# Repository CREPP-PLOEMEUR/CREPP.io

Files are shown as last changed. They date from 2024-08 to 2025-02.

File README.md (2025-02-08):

<!-- ATOC -->
# Sommaire

- [CREPP.io](#crepp.io)
  - [Configuration](#configuration)
  - [Montage de la carte](#montage-de-la-carte)
  - [Programmation de la carte](#programmation-de-la-carte)
  - [Fonctions](#fonctions)
  - [Composants](#composants)
  - [Installation et Utilisation](#installation-et-utilisation)
  - [Auteurs](#auteurs)
  - [Remerciements](#remerciements)

<!-- ATOC -->

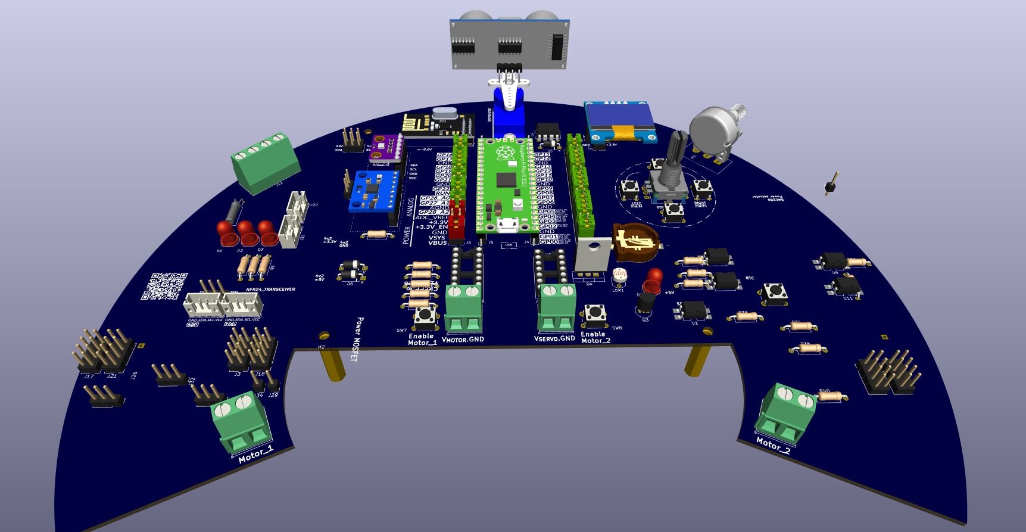
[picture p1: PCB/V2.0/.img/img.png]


# CREPP.io 

Ce projet consiste en la conception et la réalisation de cartes d'extension pour différents modules. La carte permet d'étendre les capacités de certains microcontrôleurs en ajoutant divers connecteurs, composants passifs et actifs, facilitant ainsi le développement de projets IoT (Internet des Objets). Elle est conçue pour offrir une interface facile d'utilisation pour la connexion de capteurs, d'afficheurs, de modules de communication, et d'autres périphériques.

Cette carte est le support de l'atelier Electronique Débutant pour le Club de Robotique et d'Electronique Programmable de Ploemeur (CREPP).

## Configuration

Pour programmer les cartes, nous utiliserons le framework **PlatformIO** 

Les instructions sont disponibles [sur cette page](SETUP.md)

## Montage de la carte 

Il convient tout d'abord de repérer le modèle de votre circuit :
Le numéro de version est sous le QRCode.

Les instructions de montage sont disponibles dans les fichiers suivants : 

- [Montage V1.0](PCB/V1.0/Assembly.md) - Version avec ESP12
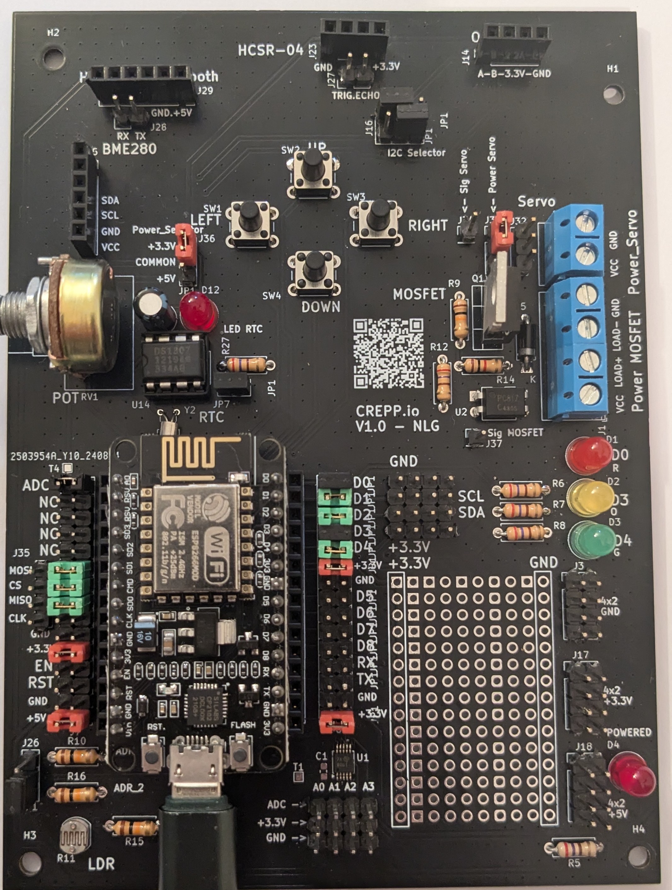
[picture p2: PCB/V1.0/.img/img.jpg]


- [Montage V1.1](PCB/V1.1/Assembly.md) - Version avec ESP12 amelioré
Description de l'image

- [Montage V2.0](PCB/V2.0/Assembly.md) - Version avec Raspberry Pi Pico-(W)
Description de l'image

## Programmation de la carte 

- [Codes V1.0](Codes/V1.X) - Code pour ESP12

- [Codes V2.0](Codes/V2.X) - Code pour Rapsberry Pi Pico W
## Fonctions

- **Connectivité étendue :** La carte propose plusieurs connecteurs (PinHeaders, Sockets, Bornes à vis) pour l'intégration facile de différents modules et capteurs.
- **Indicateurs visuels :** Des LEDs sont présentes pour indiquer l'état des signaux.
- **Contrôle manuel :** Des boutons-poussoirs permettent d'interagir directement avec la carte, utile pour des actions comme la navigation dans des menus ou la sélection de modes.
- **Horloge en temps réel :** Un module RTC (DS1307) est intégré pour fournir une mesure précise du temps.
- **Isolation et protection :** Un optocoupleur (PC817) est utilisé pour isoler électriquement certaines parties du circuit.

## Composants

- **Module ESP12 NodeMCU / Raspberry Pi Pico W:** Le cœur du projet
- **Convertisseur ADC (ADS1115) :** Permet des mesures analogiques précises.
- **Horloge RTC (DS1307) :** Fournit une temporisation en temps réel pour les applications nécessitant une précision horaire.
- **Optocoupleur (PC817) :** Assure l'isolation électrique entre différentes sections du circuit.
- **Transistor de puissance (IRF520) :** Gère la distribution de puissance pour les composants plus gourmands en énergie.

Le schéma du circuit et le design du PCB sont réalisés avec KiCad, un logiciel libre de conception de circuits électroniques. Les fichiers sources sont disponibles dans le dossier `/kicad_project`.

## Installation et Utilisation

- **Alimentation 5V ou 3.3V** pour la carte
- **Divers capteurs et modules** selon les besoins du projet (OLED, HC-SR04, BME280, etc.)

1. **Assemblez la carte** en soudant les composants selon le schéma fourni.
2. **Connectez le module** à la carte via les connecteurs dédiés.
3. **Branchez vos capteurs et modules** aux connecteurs correspondants (I2C, SPI, Analogiques, etc.).
5. **Téléversez votre code** sur le module ESP12 NodeMCU pour commencer à utiliser la carte d'extension.

Les contributions sont les bienvenues ! Si vous avez des idées d'amélioration ou des correctifs à proposer, n'hésitez pas à soumettre une Pull Request ou à ouvrir une Issue.

## Auteurs

- **LE GUERROUE Nicolas** - Concepteur principal

## Remerciements

Merci à la communauté open-source et aux contributeurs de KiCad pour avoir fourni les outils nécessaires à la réalisation de ce projet.

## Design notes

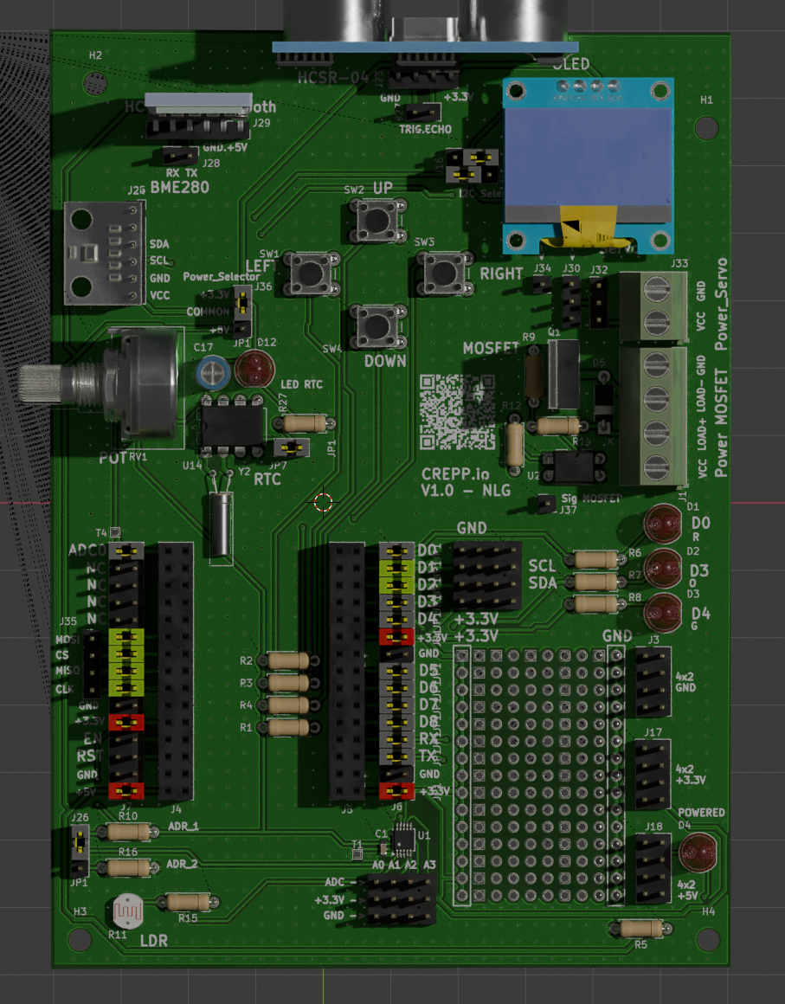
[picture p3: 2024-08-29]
Images/Top_View_BOARD.png

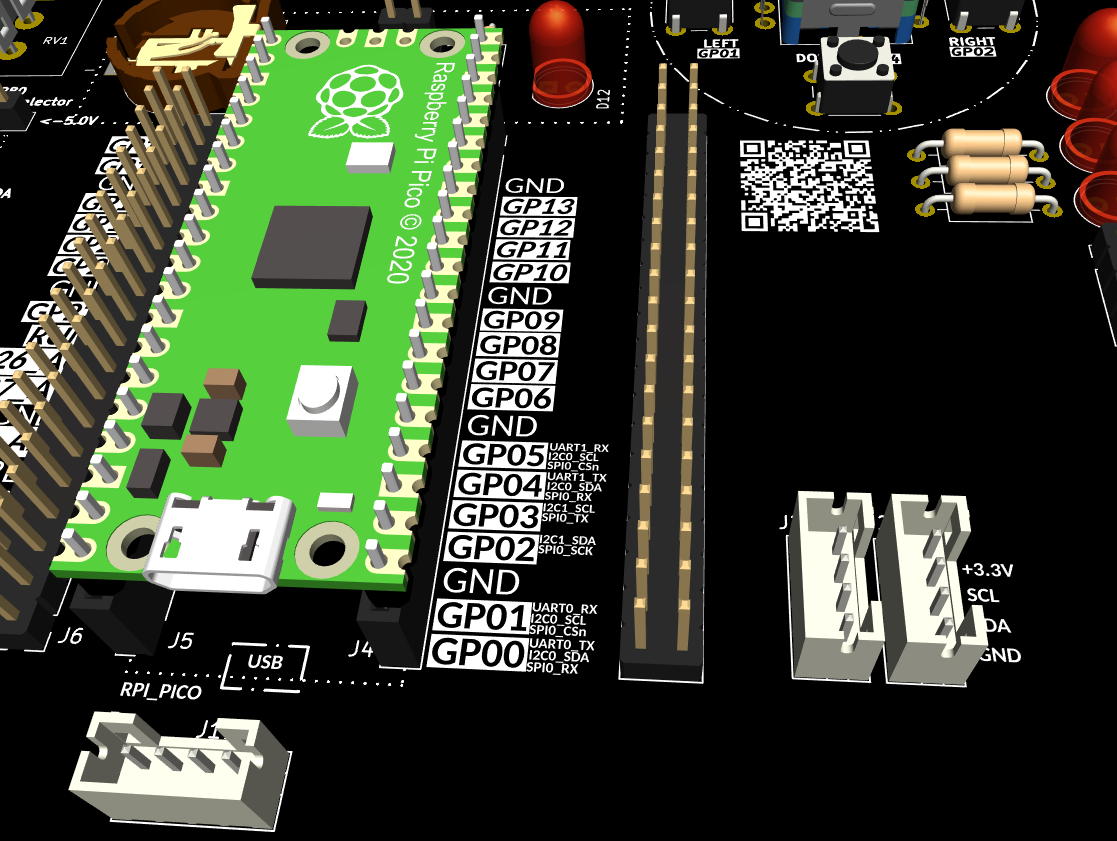
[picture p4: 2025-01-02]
PCB/V2.0/Images/Capture d’écran du 2024-11-20 23-39-54.png

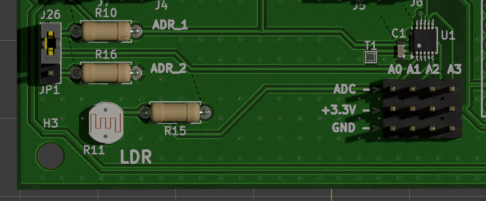
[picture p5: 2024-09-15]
Images/ADC.png

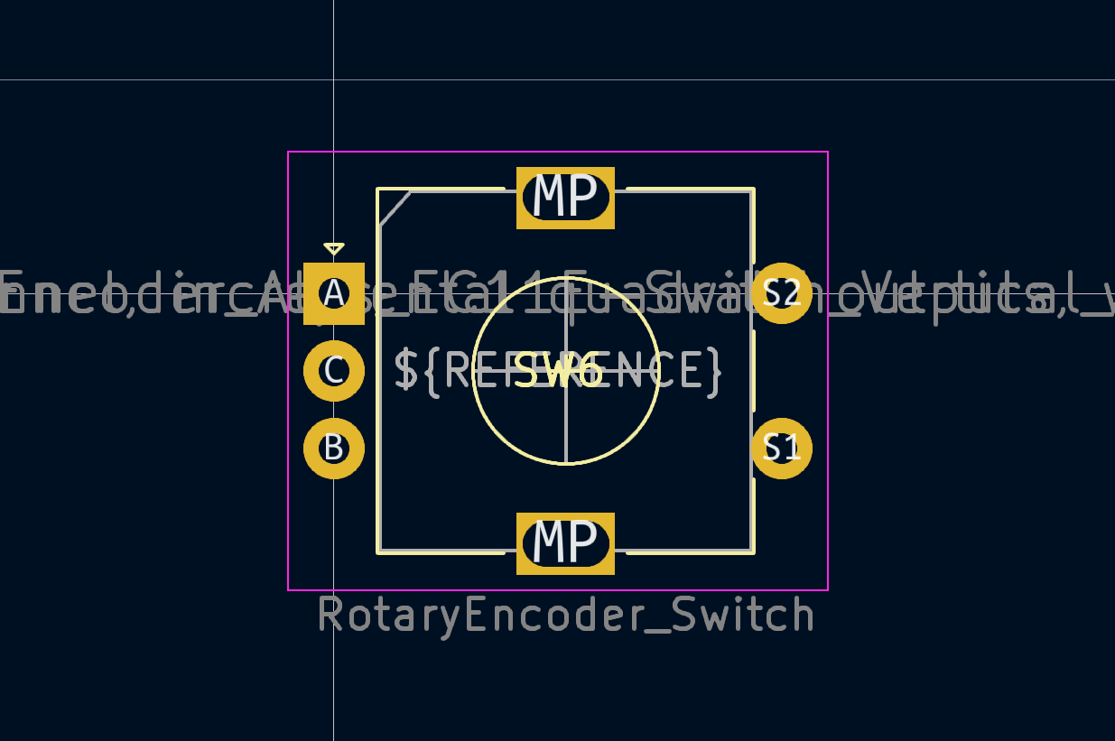
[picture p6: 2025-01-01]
PCB/V2.0/RotaryEncoder_Alps_EC11E-Switch_Vertical_H20mm.png

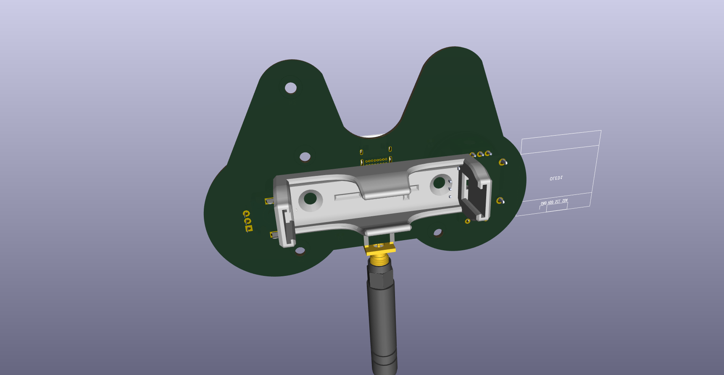
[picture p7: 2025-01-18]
PCB/CCR/CCR2.png

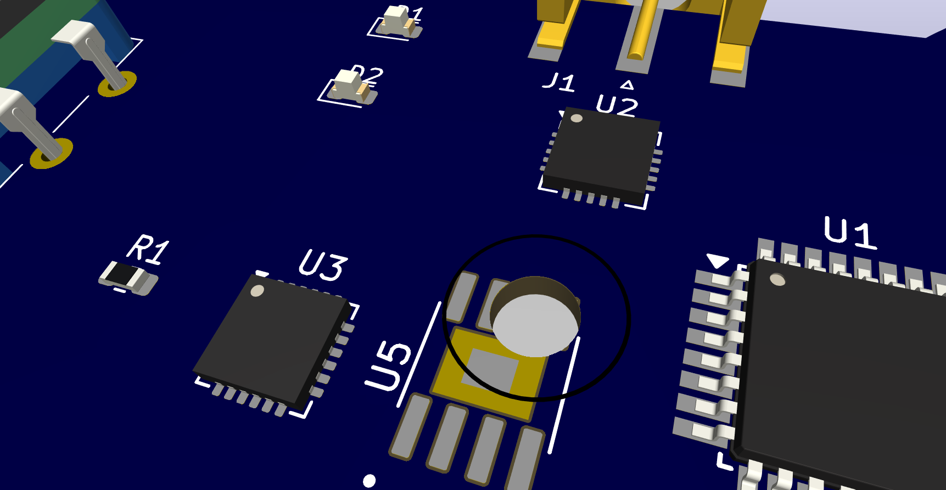
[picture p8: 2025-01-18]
PCB/CCR/CCR23.png

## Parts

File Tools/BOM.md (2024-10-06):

| Référence | Quantité | Désignation |
|---|---|---|
| R7,R27,R5,R12,R6,R8 | 6 | 270 Ω |
| RV1 | 1 | r_potentioMΩeter |
| R1,R2,R3,R16,R15,R4,R9,R10 | 8 | 10kΩ |
| R11 | 1 | r11 Ω |
| R14 | 1 | 1kΩ |
| D3,D1,D12,D4,D2 | 5 | LED |
| D5 | 1 | D |
| Q1 | 1 | IRF520 |
| J25 | 1 | BME |
| J20 | 1 | GND_Analog |
| J30 | 1 | Servo |
| J13,J15,J17,J3,J18 | 5 | Conn_02x04_Odd_Even |
| J4,J5 | 2 | Right_Connector |
| J19 | 1 | Analog_Inputs |
| J16 | 1 | I2C_Selector |
| J6,J12,J8,J9,J11,J10 | 6 | Right_Connector |
| J7 | 1 | Left_Connector |
| JP7 | 1 | Jumper |
| J33 | 1 | Screw_Terminal_01x02 |
| J23 | 1 | HC-SR |
| J21 | 1 | +3.3V_Analog |
| J35 | 1 | SPI_Connector |
| J29 | 1 | Conn_01x06_Socket |
| J36 | 1 | Power_Selector |
| J24 | 1 | BME_VIRTUAL |
| J26 | 1 | Addr_Selector |
| J37 | 1 | Sig_MOSFET |
| J1 | 1 | Screw_Terminal_01x04 |
| J32 | 1 | Power_Servo_Selector |
| J27 | 1 | SIG_HCSR04 |
| J14 | 1 | OLED_SOCKET |
| J28 | 1 | SIG_HC-05 |
| J34 | 1 | Sig_Servo |
| SW4 | 1 | SW_Down |
| SW2 | 1 | SW_Up |
| T1,T4 | 2 | TestPoint |
| U2 | 1 | PC817 |
| SW3 | 1 | SW_Right |
| U1 | 1 | ADS1115IDGS |
| C17 | 1 | 100nF |
| Y2 | 1 | 16MHz |
| SW1 | 1 | SW_Left |
| C1 | 1 | 100nF |
| U14 | 1 | DS1307+ |

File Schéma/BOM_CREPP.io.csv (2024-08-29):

Id | Référence | Empreinte | Quantité | Désignation | Fournisseur et réf
1 | R7,R27,R5,R12,R6,R8 | R_Axial_DIN0207_L6.3mm_D2.5mm_P7.62mm_Horizontal | 6 | 270
2 | JP1,JP1,JP1,JP1,JP1,JP1,JP1,JP1,JP1,JP1,JP1,JP1,JP1,JP1,JP1,JP1,JP1,JP1,JP1,JP1,JP1,JP1,JP1,JP1,JP1 | PinHeader_2x01_P2.54mm_Vertical | 25 | J2.54MM
3 | J25 | PinSocket_1x06_P2.54mm_Vertical | 1 | BME
4 | RV1 | Potentiometer_Alps_RK163_Single_Horizontal | 1 | R_Potentiometer
5 | J20 | PinHeader_1x04_P2.54mm_Vertical | 1 | GND_Analog
6 | J30 | PinHeader_1x03_P2.54mm_Vertical | 1 | Servo
7 | J13,J15,J17,J3,J18 | PinHeader_2x04_P2.54mm_Vertical | 5 | Conn_02x04_Odd_Even
8 | D3,D1,D12,D4,D2 | LED_D5.0mm | 5 | LED
9 | SW4 | SW_PUSH_6mm | 1 | SW_Down
10 | J4,J5 | PinSocket_2x15_P2.54mm_Vertical | 2 | Right_Connector
11 | J19 | PinHeader_1x04_P2.54mm_Vertical | 1 | Analog_Inputs
12 | J16 | PinHeader_2x03_P2.54mm_Vertical | 1 | I2C_Selector
13 | J22 | PinSocket_1x04_P2.54mm_Vertical | 1 | OLED_SOCKET_VIRTUAL
14 | J6,J12,J8,J9,J11,J10 | PinHeader_2x15_P2.54mm_Vertical | 6 | Right_Connector
15 | J7 | PinHeader_2x15_P2.54mm_Vertical | 1 | Left_Connector
16 | JP7 | PinHeader_1x02_P2.54mm_Vertical | 1 | Jumper
17 | J33 | TerminalBlock_Phoenix_MKDS-1,5-2_1x02_P5.00mm_Horizontal | 1 | Screw_Terminal_01x02
18 | SW2 | SW_PUSH_6mm | 1 | SW_Up
19 | R1,R2,R3,R16,R15,R4,R9,R10 | R_Axial_DIN0207_L6.3mm_D2.5mm_P7.62mm_Horizontal | 8 | 10k
20 | J23 | PinSocket_1x04_P2.54mm_Vertical | 1 | HC-SR
21 | T1,T4 | TestPoint_Pad_1.0x1.0mm | 2 | TestPoint
22 | J21 | PinHeader_1x04_P2.54mm_Vertical | 1 | +3.3V_Analog
23 | U2 | DIP-4_W7.62mm | 1 | PC817
24 | J35 | PinHeader_1x04_P2.54mm_Vertical | 1 | SPI_Connector
25 | SW3 | SW_PUSH_6mm | 1 | SW_Right
26 | D5 | D_A-405_P7.62mm_Horizontal | 1 | D
27 | U1 | TSSOP-10_3x3mm_P0.5mm | 1 | ADS1115IDGS
28 | J29 | PinSocket_1x06_P2.54mm_Vertical | 1 | Conn_01x06_Socket
29 | J36 | PinHeader_1x03_P2.54mm_Vertical | 1 | Power_Selector
30 | J24 | PinSocket_1x06_P2.54mm_Vertical | 1 | BME_VIRTUAL
31 | J26 | PinHeader_1x03_P2.54mm_Vertical | 1 | Addr_Selector
32 | J37 | PinHeader_1x01_P2.54mm_Vertical | 1 | Sig_MOSFET
33 | J31 | PinSocket_1x04_P2.54mm_Vertical | 1 | HC-05_VIRTUAL
34 | J1 | TerminalBlock_Phoenix_MKDS-1,5-4-5.08_1x04_P5.08mm_Horizontal | 1 | Screw_Terminal_01x04
35 | C17 | C_Radial_D5.0mm_H11.0mm_P2.00mm | 1 | 100nF
36 | J32 | PinHeader_1x03_P2.54mm_Vertical | 1 | Power_Servo_Selector
37 | J27 | PinHeader_1x02_P2.54mm_Vertical | 1 | SIG_HCSR04
38 | Y2 | Crystal_AT310_D3.0mm_L10.0mm_Horizontal | 1 | 16MHz
39 | Q1 | TO-220-3_Vertical | 1 | IRF520
40 | SW1 | SW_PUSH_6mm | 1 | SW_Left
41 | C1 | C_0603_1608Metric | 1 | 100nF
42 | J14 | PinSocket_1x04_P2.54mm_Vertical | 1 | OLED_SOCKET
43 | J28 | PinHeader_1x02_P2.54mm_Vertical | 1 | SIG_HC-05
44 | R11 | R_LDR_5.1x4.3mm_P3.4mm_Vertical | 1 | LDR07
45 | J34 | PinHeader_1x01_P2.54mm_Vertical | 1 | Sig_Servo
46 | R14 | R_Axial_DIN0207_L6.3mm_D2.5mm_P7.62mm_Horizontal | 1 | 1k
47 | U14 | DIP-8_W7.62mm | 1 | DS1307+
48 | J2 | PinSocket_1x04_P2.54mm_Vertical | 1 | HC-SR04_VIRTUAL

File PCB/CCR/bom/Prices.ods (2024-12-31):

Reference | Description | Quantité par carte | Prix de lot | Quantité par lot | Lot nécessaires | Quantité suffisantes | Prix unitaire | Livraison pour N cartes | Prix sur la carte | Quantité de cartes | 30
Puce NRF24 | NRF24 | 1 | 1,55 | 1 | 30 | OK | 1,55 | 10,8 | 1,55
Led rouges | Led rouge | 3 | 3,49 | 100 | 1 | OK | 0,0349 | 0 | 0,1047 |  |  | https://fr.aliexpress.com/item/1005003323707856.html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
Led vertes | LED vertes | 1 | 3,49 | 100 | 1 | OK | 0,0349 | 0 | 0,0349
Led jaunes | LED jaunes | 1 | 3,49 | 100 | 1 | OK | 0,0349 | 0 | 0,0349
L293D | L293D | 1 | 1,48 | 5 | 6 | OK | 0,296 | 2,93 | 0,296 |  |  | https://fr.aliexpress.com/item/1005007983665361.html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
Support DIP-16 |  | 1 | 1,14 | 20 | 2 | OK | 0,057 | 3,93 | 0,057
Connecteur JST 2mm |  | 2 | 2,72 | 100 | 1 | OK | 0,0272 | 0 | 0,0544 |  |  | https://fr.aliexpress.com/item/1005003431613901.html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
RPI pico |  | 1 | 8,28 | 1 | 30 | OK | 8,28 | 0 | 8,28
KF301-2P |  | 7 | 1,29 | 10 | 21 | OK | 0,129 | 0 | 0,903 |  |  | https://fr.aliexpress.com/item/1005008001886478.html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
OLED |  | 1 | 1,39 | 1 | 30 | OK | 1,39 | 0 | 1,39
MPU-6050 | Accéléromètre | 1 | 0,99 | 1 | 30 | OK | 0,99 | 0 | 0,99
74HC04 | Porte inverseuse | 1 | 1,91 | 10 | 3 | OK | 0,191 | 0 | 0,191 |  |  | https://fr.aliexpress.com/item/1005006870781173.html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
encodeur rotatif |  | 1 | 2,69 | 5 | 6 | OK | 0,538 | 0 | 0,538 |  |  | https://fr.aliexpress.com/item/1005007644083514.html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
Bouton poussoir |  | 7 | 1,44 | 50 | 5 | OK | 0,0288 | 2,83 | 0,2016
Moteur DC |  | 2 | 19,89 | 20 | 3 | OK | 0,9945 | 2 | 1,989 |  |  | https://fr.aliexpress.com/item/1005007447267197.html?scm_id=1007.40196.404796.0&scm-url=1007.40196.404796.0
BME280 | Attention vérifiez bien le voltage de fonctionnement de votre capteur, il en existe 2 versions. le capteur 3,3V comporte 6 broches, celui à 5V n'en possède que 4 | 1 | 3 | 1 | 30 | OK | 3 | 0 | 3
Résistances de 10k 1/4W |  | 10 | 0,58 | 100 | 3 | OK | 0,0058 | 2,61 | 0,058 |  |  | https://fr.aliexpress.com/item/1005003818444423.html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
Résistances de 1k 1/4W |  | 10 | 0,58 | 100 | 3 | OK | 0,0058 | 2,61 | 0,058 |  |  | https://fr.aliexpress.com/item/1005003818444423.html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
Résistances de 270 1/4W |  | 1 | 0,58 | 100 | 3 | OK | 0,0058 | 2,61 | 0,0058
Optocoupleur PC817 |  | 5 | 2,7 | 50 | 3 | OK | 0,054 | 0 | 0,27 |  |  | https://fr.aliexpress.com/item/1005006140298503.html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
HC-SR04 |  | 1 | 9,52 | 10 | 3 | OK | 0,952 | 0 | 0,952 |  |  | https://fr.aliexpress.com/item/1005007849944952.html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
Connecteur 2.54mm 40 |  | 6 | 2,42 | 20 | 10 | OK | 0,121 | 0 | 0,726
RTC DS1302 |  | 1 | 1,42 | 10 | 3 | OK | 0,142 | 0 | 0,142
 |  |  |  |  |  |  |  | 30,32 | 21,8263
 |  |  |  |  |  |  | Livraison par carte | 1,01066666666667
 |  |  |  |  |  |  | prix du PCB unitaire | 5
 |  |  |  |  |  |  | Total pour une carte | 27,8369666666667
 |  |  |  |  |  |  | Total Commande |  | 835,109

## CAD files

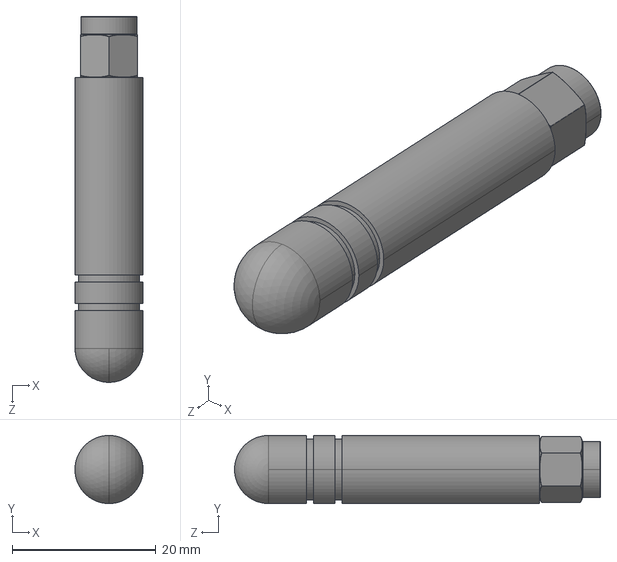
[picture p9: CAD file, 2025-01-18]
PCB/CCR/Parts/SMA_Antenna_3D.step
9.50 x 9.50 x 51.0 mm

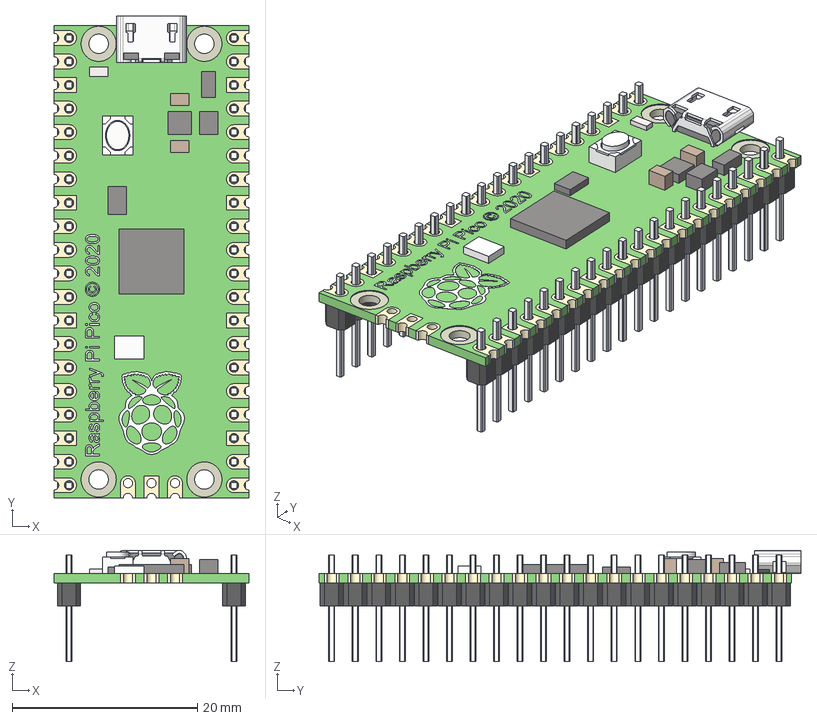
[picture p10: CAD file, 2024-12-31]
PCB/V2.0/VIRTUAL_PICO.step
21.0 x 52.0 x 12.0 mm
ножка x 20
ножка v3(Mirror) x 20

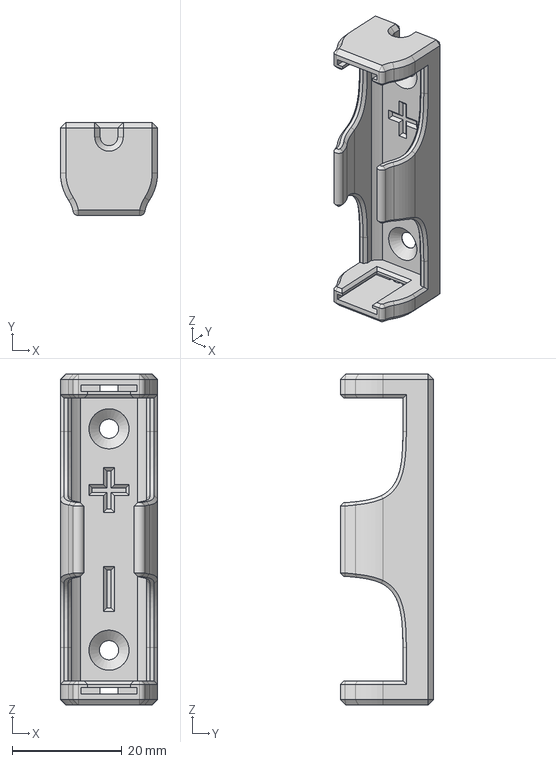
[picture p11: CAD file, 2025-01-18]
PCB/CCR/Parts/AA_14500 Battery Holder.step
17.7 x 17.0 x 60.3 mm

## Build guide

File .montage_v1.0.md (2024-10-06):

[Revenir sur la page d'accueil(github.com/CREPP-PLOEMEUR/crepp.io)

# Instructions de montage

Les instructions de montage concernent la version **1.0**

# Liste des composants

| Référence | Quantité | Désignation |
|---|---|---|
| D3,D1,D12,D4,D2 | 5 | LED |
| J14 | 1 | OLED_SOCKET |
| R7,R27,R5,R12,R6,R8 | 6 | 270 |
| J25 | 1 | BME |
| RV1 | 1 | R_Potentiometer |
| J20 | 1 | GND_Analog |
| J30 | 1 | Servo |
| J13,J15,J17,J3,J18 | 5 | Conn_02x04_Odd_Even |
| SW4 | 1 | SW_Down |
| J4,J5 | 2 | Right_Connector |
| J19 | 1 | Analog_Inputs |
| J16 | 1 | I2C_Selector |
| J6,J12,J8,J9,J11,J10 | 6 | Right_Connector |
| J7 | 1 | Left_Connector |
| JP7 | 1 | Jumper |
| J33 | 1 | Screw_Terminal_01x02 |
| SW2 | 1 | SW_Up |
| R1,R2,R3,R16,R15,R4,R9,R10 | 8 | 10k |
| J23 | 1 | HC-SR |
| T1,T4 | 2 | TestPoint |
| J21 | 1 | +3.3V_Analog |
| U2 | 1 | PC817 |
| J35 | 1 | SPI_Connector |
| SW3 | 1 | SW_Right |
| D5 | 1 | D |
| U1 | 1 | ADS1115IDGS |
| J29 | 1 | Conn_01x06_Socket |
| J36 | 1 | Power_Selector |
| J24 | 1 | BME_VIRTUAL |
| J26 | 1 | Addr_Selector |
| J37 | 1 | Sig_MOSFET |
| J1 | 1 | Screw_Terminal_01x04 |
| C17 | 1 | 100nF |
| J32 | 1 | Power_Servo_Selector |
| J27 | 1 | SIG_HCSR04 |
| Y2 | 1 | 16MHz |
| Q1 | 1 | IRF520 |
| SW1 | 1 | SW_Left |
| C1 | 1 | 100nF |
| J28 | 1 | SIG_HC-05 |
| R11 | 1 | R11 |
| J34 | 1 | Sig_Servo |
| R14 | 1 | 1k |
| U14 | 1 | DS1307+ |

# Remarque importante

Lors de la programmation de la carte, il ne faut pas que le Jumper D8 soit placé sur
son emplacement. Ou bien il faut presser le bouton LEFT lors du téléversement.

Ce problème est du au fait que la broche D8 doit être à l'état BAS lors de la programmation 
et que les boutons sont câblés avec une résistance qui impose un niveau HAUT par défaut.

# Remarques générales

On commence par monter les composants du plus bas au plus haut.

C'est à dire que si il y a des composants montés en surfaces (résistances, circuits intégrés, condensateurs...), il vaut mieux les monter 
car les composants plus hauts vont gêner.
On fait généralement les résistances traversantes dans un second ordre.

On termine donc par les grands composants (potentiomètres).

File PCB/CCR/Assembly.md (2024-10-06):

<!-- ATOC -->
# Sommaire

- [Instructions de montage](#instructions-de-montage)
- [Liste des composants](#liste-des-composants)
- [Plan de montage](#plan-de-montage)
- [Remarque importante](#remarque-importante)
- [Remarques générales](#remarques-generales)

<!-- ATOC -->
[Revenir sur la page d'accueil](http://github.com/CREPP-PLOEMEUR/crepp.io)

# Instructions de montage

Les instructions de montage concernent la version **1.0**.
Veuillez lire l'ensemble de cette page avant de commencer le montage.

# Liste des composants

| Référence | Quantité | Désignation |
|---|---|---|
| R7,R27,R5,R12,R6,R8 | 6 | 270 Ω |
| RV1 | 1 | r_potentiometer |
| R1,R2,R3,R16,R15,R4,R9,R10 | 8 | 10kΩ |
| R11 | 1 | r11 Ω |
| R14 | 1 | 1kΩ |
| D3,D1,D12,D4,D2 | 5 | LED |
| D5 | 1 | D |
| Q1 | 1 | IRF520 |
| J25 | 1 | BME |
| J20 | 1 | GND_Analog |
| J30 | 1 | Servo |
| J13,J15,J17,J3,J18 | 5 | Conn_02x04_Odd_Even |
| J4,J5 | 2 | Right_Connector |
| J19 | 1 | Analog_Inputs |
| J16 | 1 | I2C_Selector |
| J6,J12,J8,J9,J11,J10 | 6 | Right_Connector |
| J7 | 1 | Left_Connector |
| JP7 | 1 | Jumper |
| J33 | 1 | Screw_Terminal_01x02 |
| J23 | 1 | HC-SR |
| J21 | 1 | +3.3V_Analog |
| J35 | 1 | SPI_Connector |
| J29 | 1 | Conn_01x06_Socket |
| J36 | 1 | Power_Selector |
| J24 | 1 | BME_VIRTUAL |
| J26 | 1 | Addr_Selector |
| J37 | 1 | Sig_MOSFET |
| J1 | 1 | Screw_Terminal_01x04 |
| J32 | 1 | Power_Servo_Selector |
| J27 | 1 | SIG_HCSR04 |
| J14 | 1 | OLED_SOCKET |
| J28 | 1 | SIG_HC-05 |
| J34 | 1 | Sig_Servo |
| SW4 | 1 | SW_Down |
| SW2 | 1 | SW_Up |
| T1,T4 | 2 | TestPoint |
| U2 | 1 | PC817 |
| SW3 | 1 | SW_Right |
| U1 | 1 | ADS1115IDGS |
| C17 | 1 | 100nF |
| Y2 | 1 | 16MHz |
| SW1 | 1 | SW_Left |
| C1 | 1 | 100nF |
| U14 | 1 | DS1307+ |

# Plan de montage

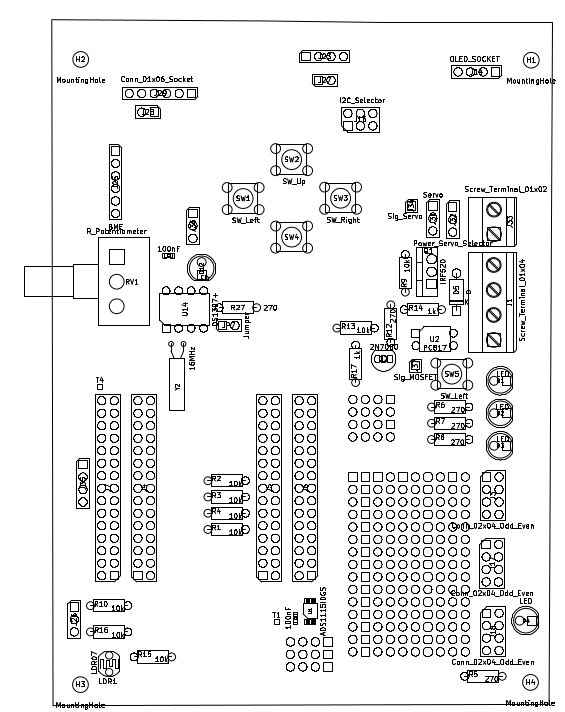
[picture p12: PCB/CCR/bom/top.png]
Plan de montage de la face supérieure


# Remarque importante

Lors de la programmation de la carte, il ne faut pas que le Jumper D8 soit placé sur
son emplacement. Ou bien il faut presser le bouton LEFT lors du téléversement.

Ce problème est du au fait que la broche D8 doit être à l'état BAS lors de la programmation 
et que les boutons sont câblés avec une résistance qui impose un niveau HAUT par défaut.

# Remarques générales

On commence par monter les composants du plus bas au plus haut.

C'est à dire que si il y a des composants montés en surfaces (résistances, circuits intégrés, condensateurs...), il vaut mieux les monter 
car les composants plus hauts vont gêner.
On fait généralement les résistances traversantes dans un second ordre.

On termine donc par les grands composants (potentiomètres).

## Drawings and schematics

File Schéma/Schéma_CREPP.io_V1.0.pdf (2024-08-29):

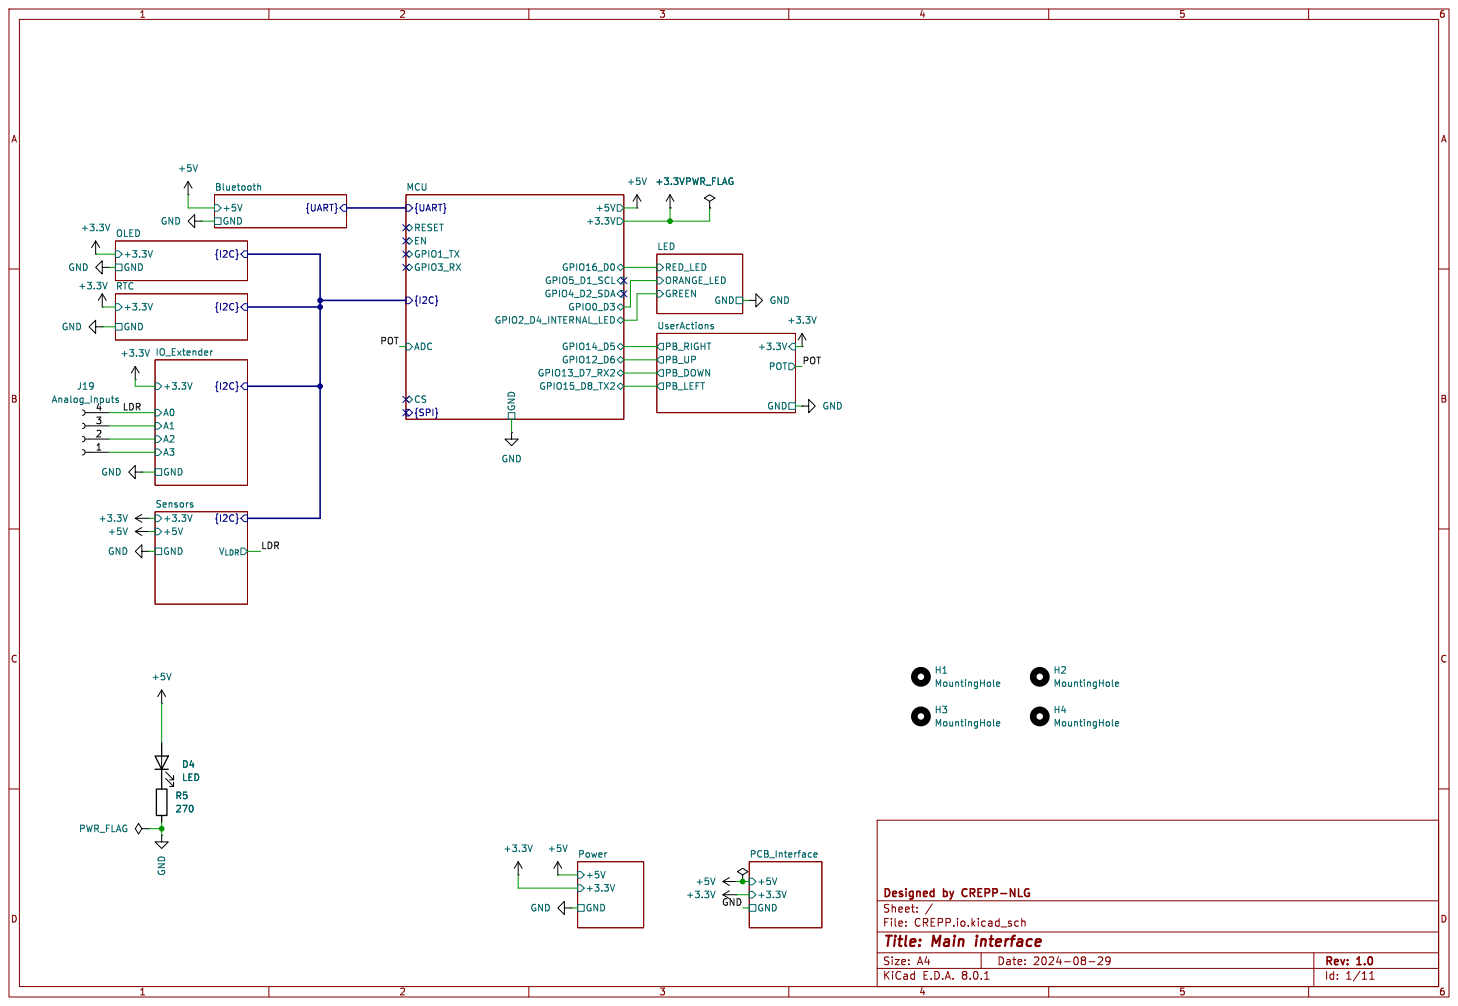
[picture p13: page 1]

Id: 1/11 Title: Main interface

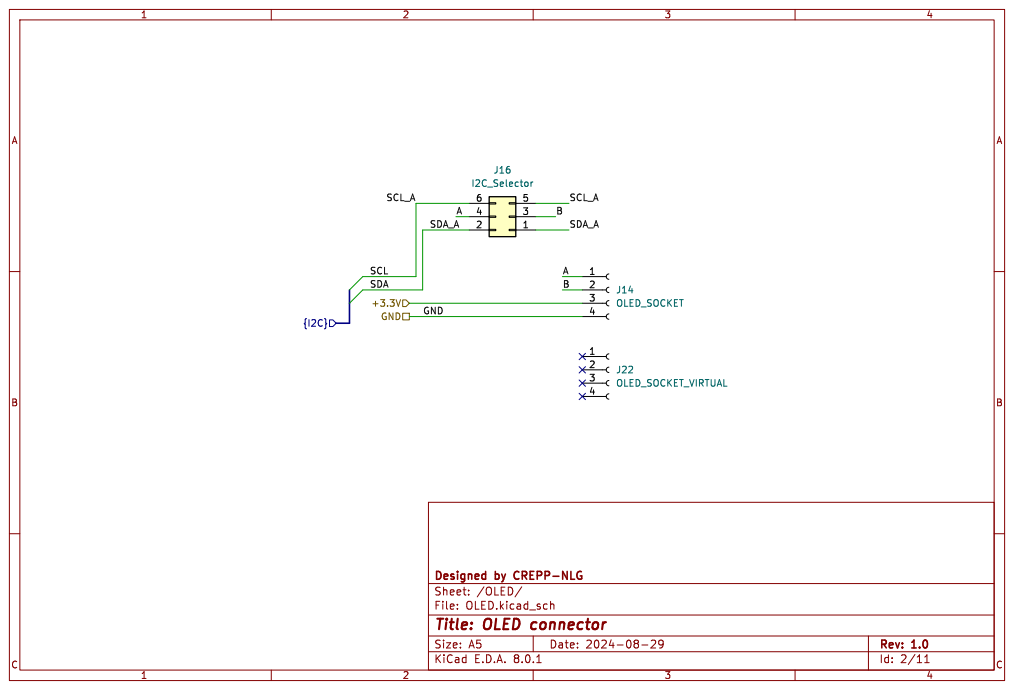
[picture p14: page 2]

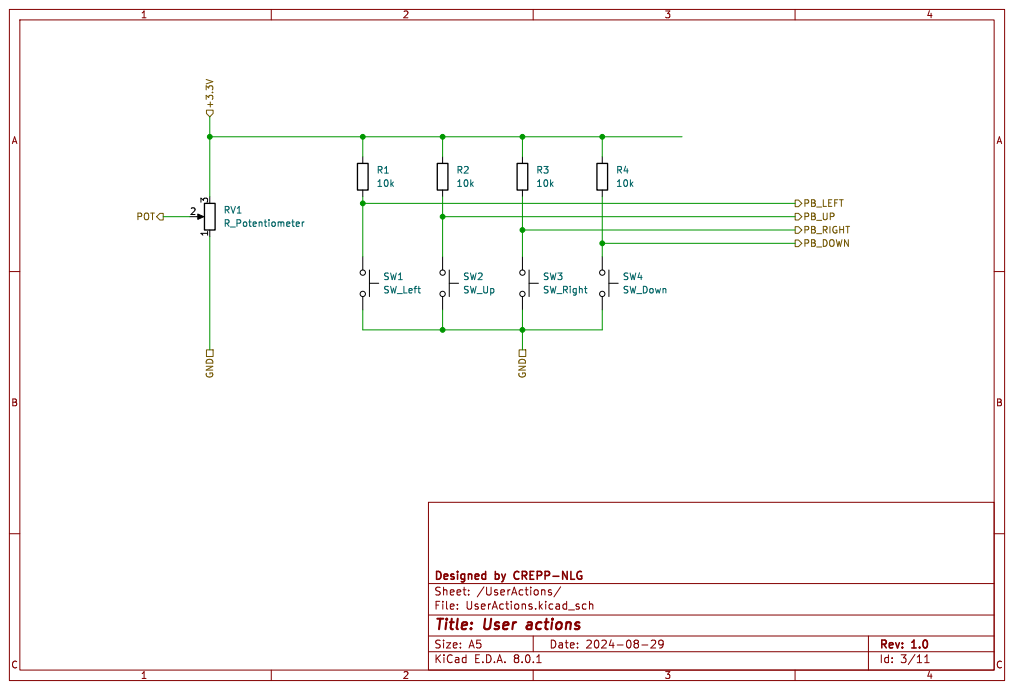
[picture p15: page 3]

Id: 3/11 Title: User actions

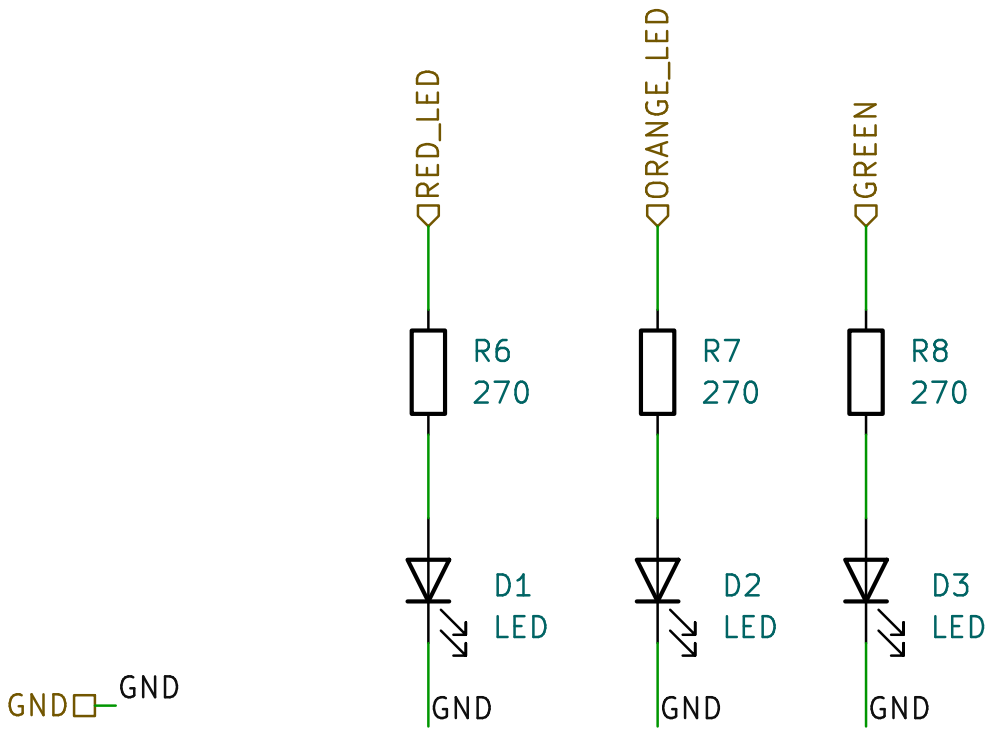
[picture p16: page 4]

Id: 4/11 Title: LED interface

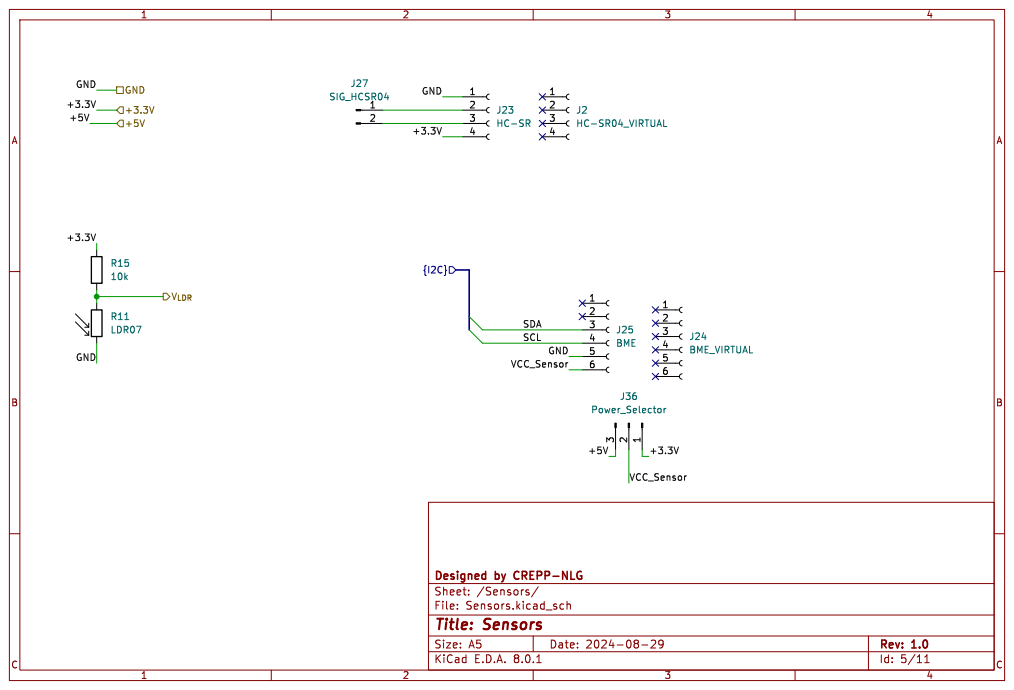
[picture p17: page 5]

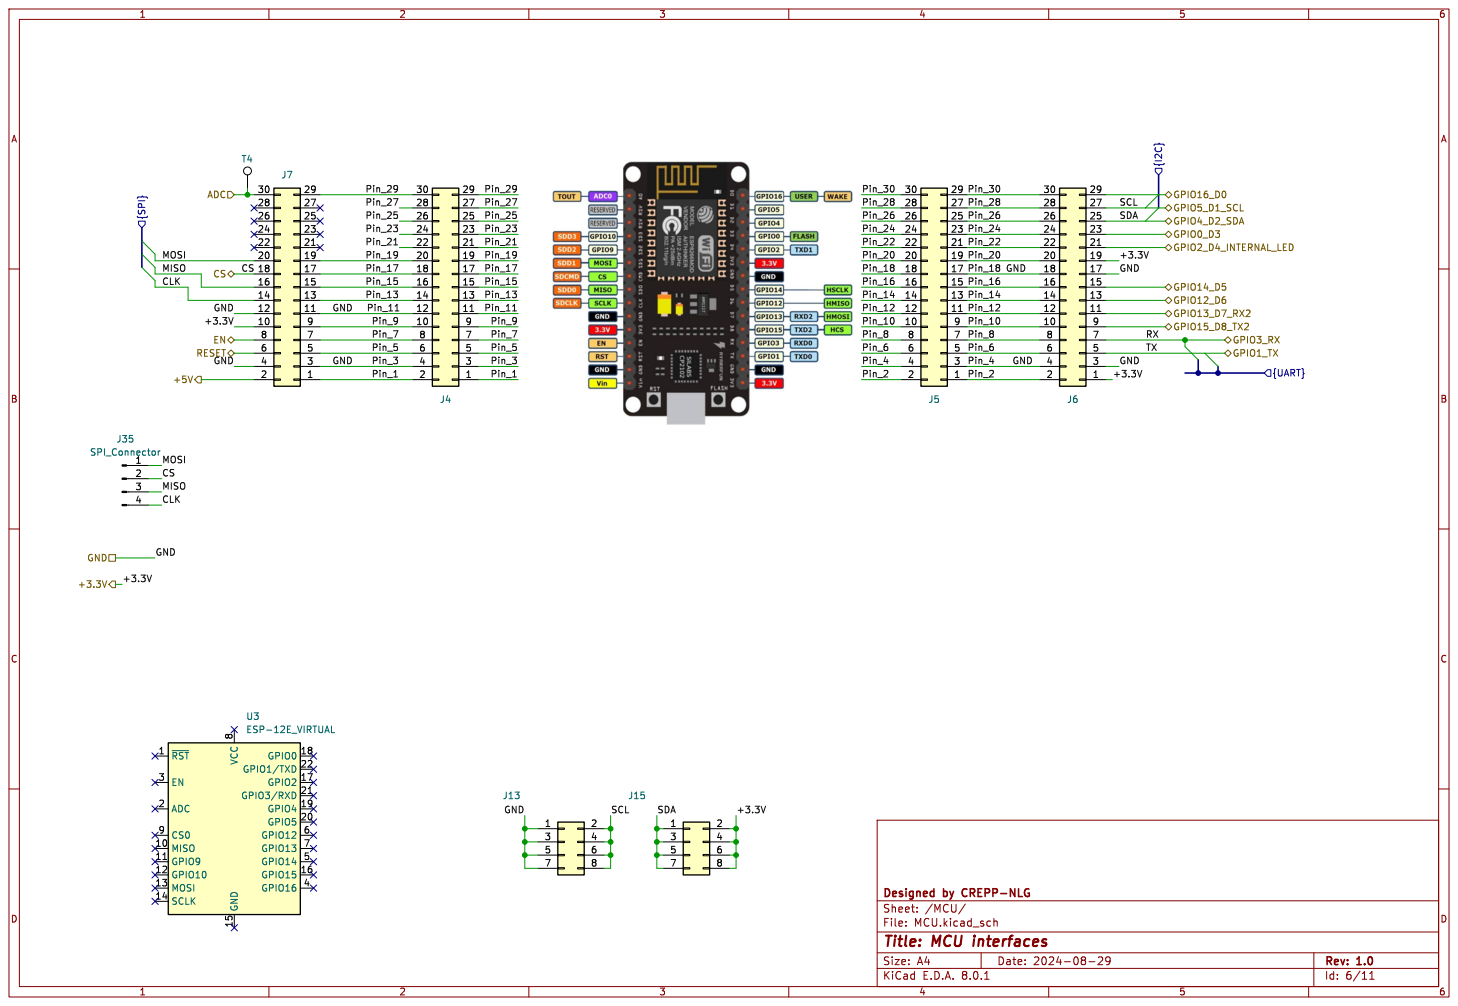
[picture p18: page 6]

Pin_22 Pin_6 Pin_26 Pin_20 Pin_18 GND MOSI CLK MISO

Id: 6/11 Title: MCU interfaces

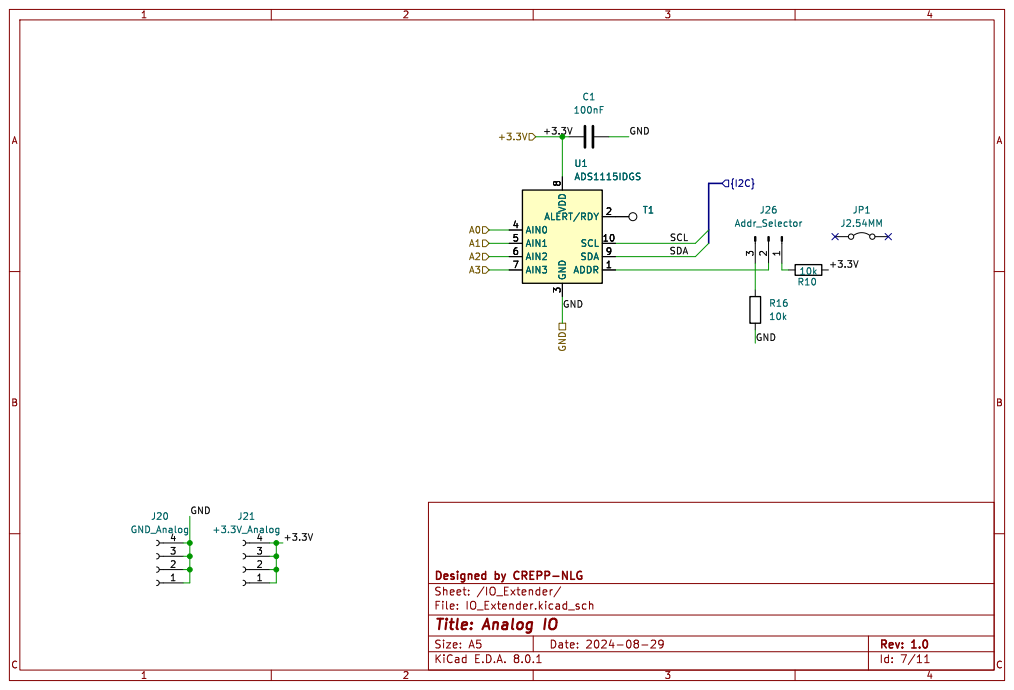
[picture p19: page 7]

Id: 7/11 Title: Analog IO

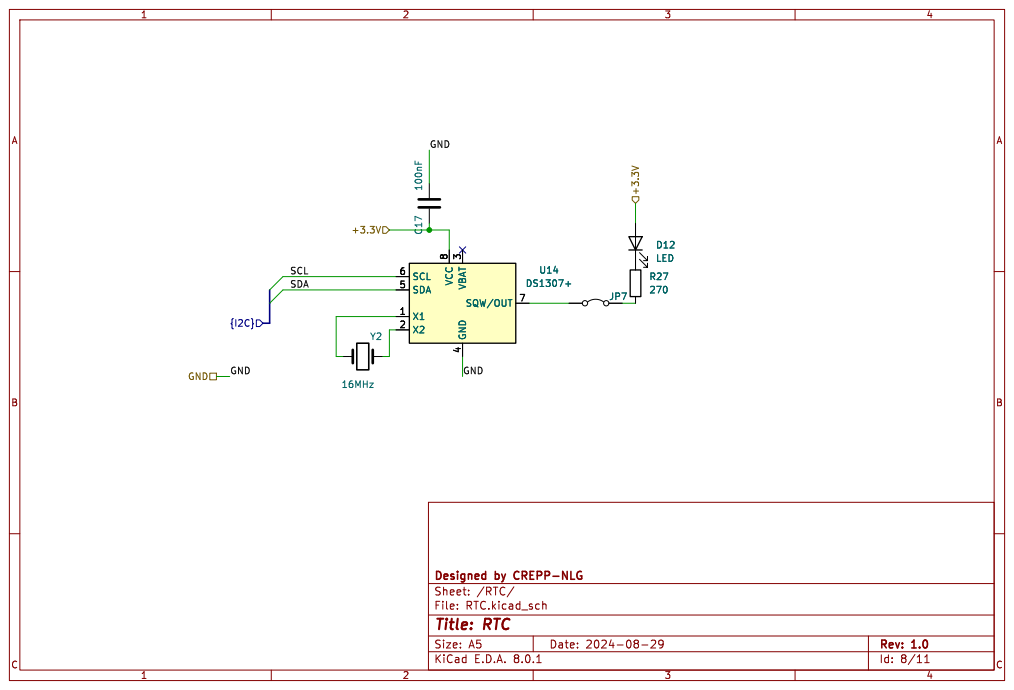
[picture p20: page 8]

4 SDA 5 SCL 6 SQW/OUT 7 VCC

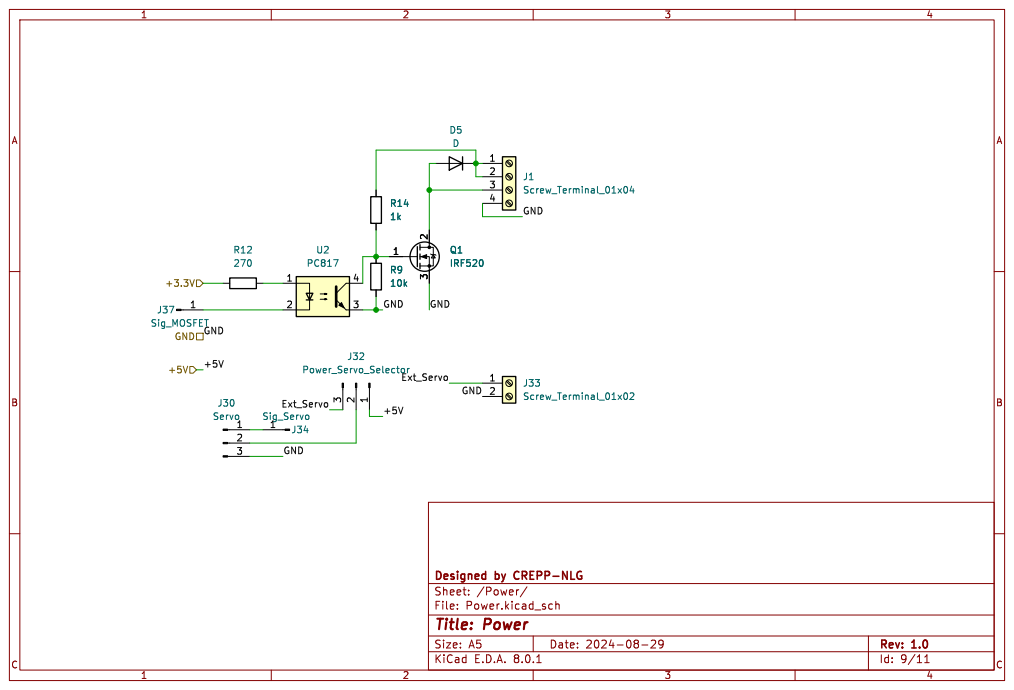
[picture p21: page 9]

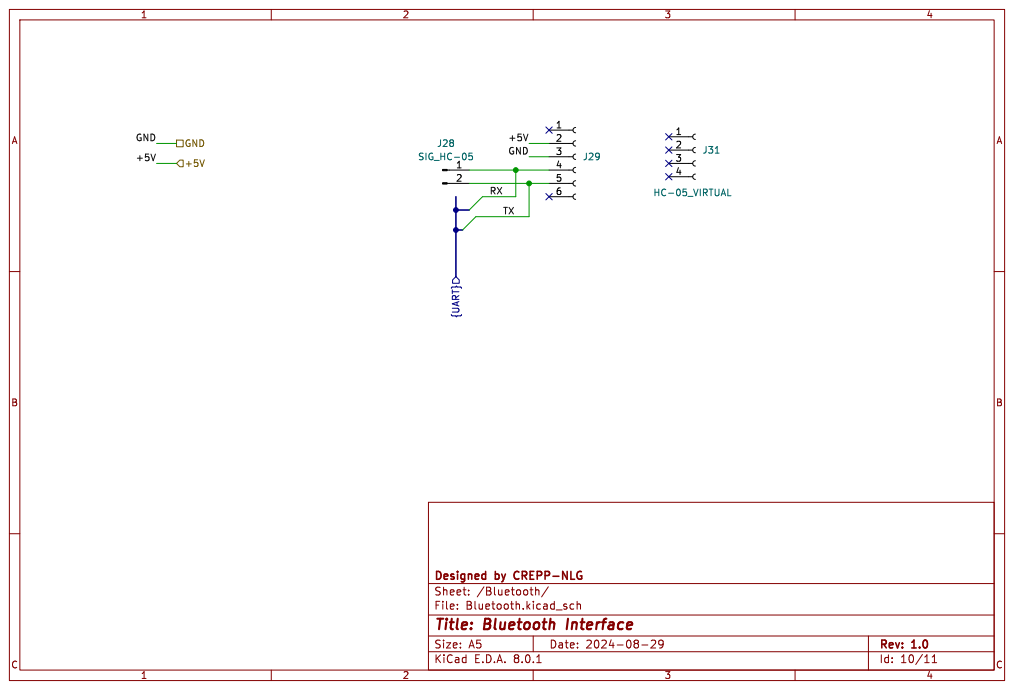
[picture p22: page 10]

Id: 10/11 Title: Bluetooth Interface

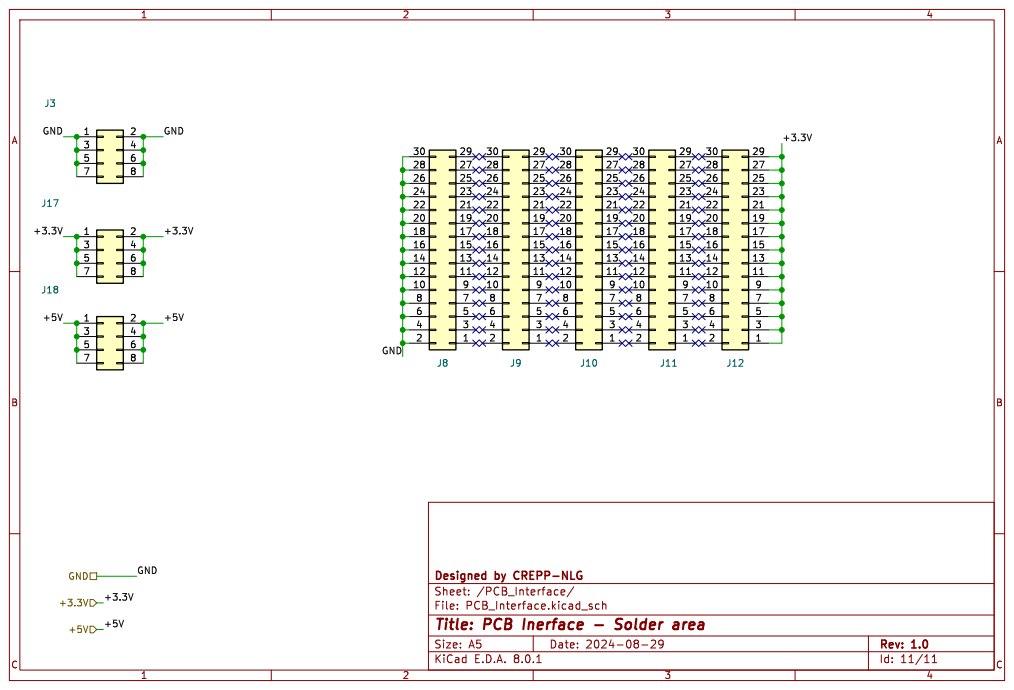
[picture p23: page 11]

Id: 11/11 Title: PCB Inerface - Solder area

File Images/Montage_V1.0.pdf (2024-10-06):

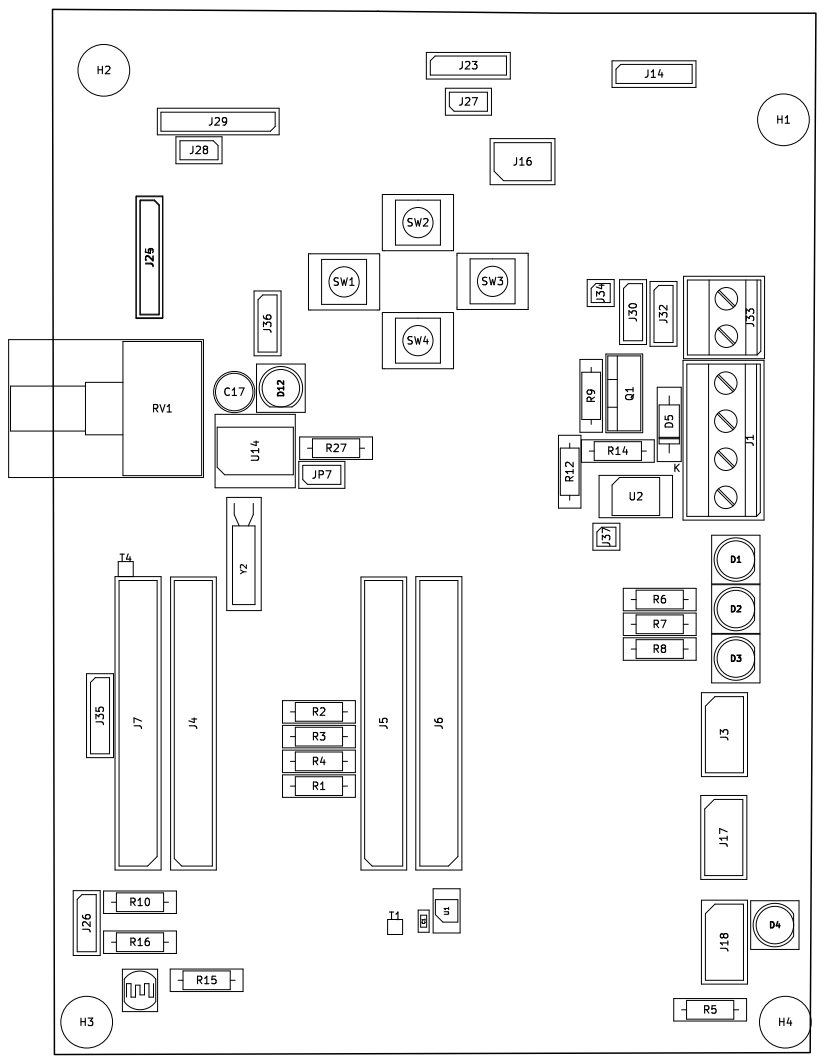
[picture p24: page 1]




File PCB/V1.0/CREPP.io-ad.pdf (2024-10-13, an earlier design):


Id: 1/1 Title: File: CREPP.io.kicad_pcb Sheet:

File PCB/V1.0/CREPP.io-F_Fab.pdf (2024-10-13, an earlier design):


Id: 1/1 Title: File: CREPP.io.kicad_pcb Sheet:



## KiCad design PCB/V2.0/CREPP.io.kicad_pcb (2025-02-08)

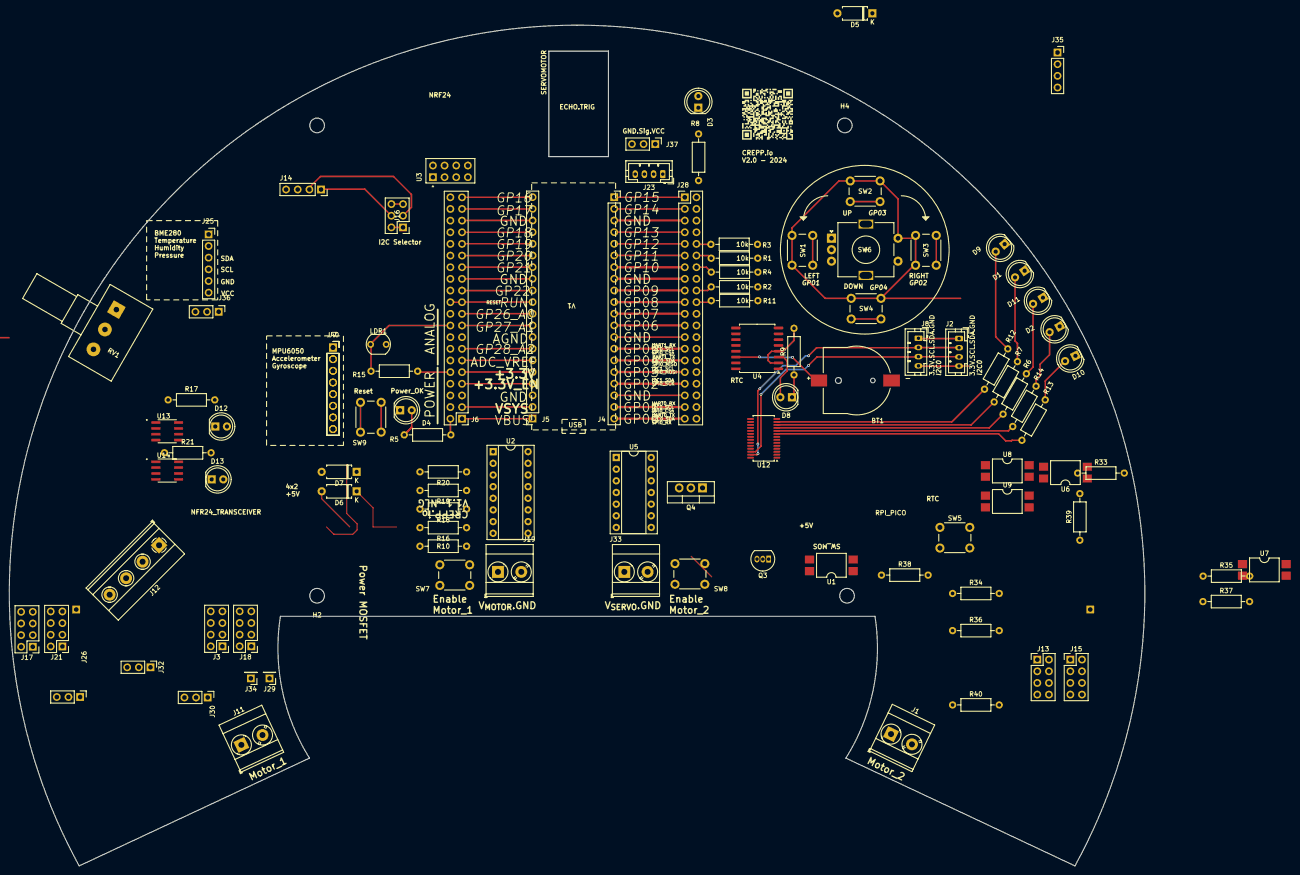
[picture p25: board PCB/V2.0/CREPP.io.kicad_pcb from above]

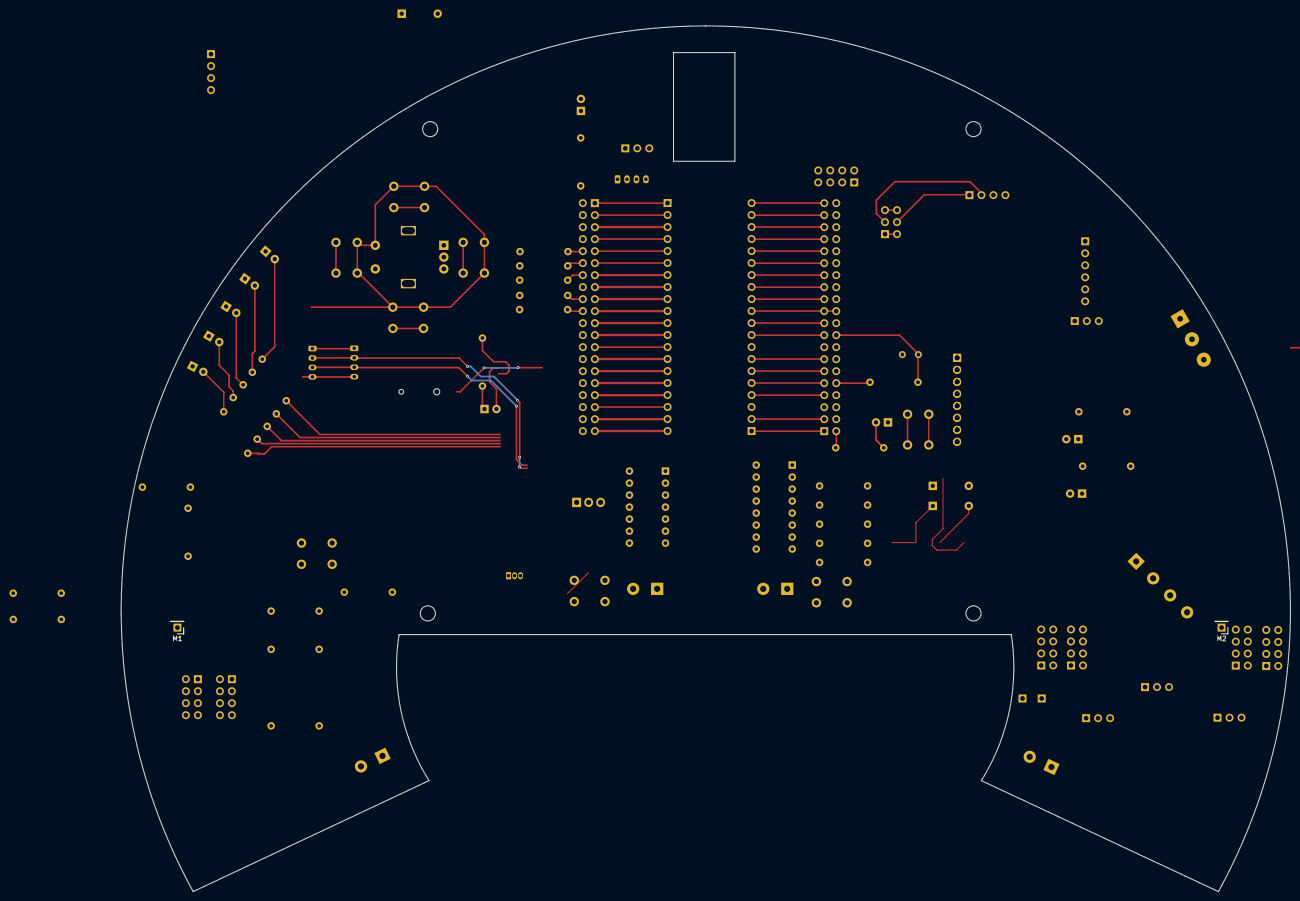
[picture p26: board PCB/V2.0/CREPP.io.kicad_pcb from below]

Board: 2 copper layers, 247.5 x 183.2 mm, 144 parts (2 on the bottom side), 124 nets.

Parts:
BT1: Battery_Cell; MPD_BC501SM-TR
D1, D9: LED_Red; LED_D5.0mm_Red
D2, D11: LED_Orange; LED_D5.0mm_Orange
D3, D4, D10: LED_Green; LED_D5.0mm_Green
D5, D6, D7: D; D_A-405_P7.62mm_Horizontal
D8, D12, D13: LED; LED_D5.0mm
H1, H2, H3, H4: MountingHole; MountingHole_3.2mm_M3
J1, J11, J19, J33: Screw_Terminal_01x02; TerminalBlock_Phoenix_MKDS-3-2-5.08_1x02_P5.08mm_Horizontal
J2, J8, J23: Coon_01x04_Pin_2mm; JST_PH_B4B-PH-K_1x04_P2.00mm_Vertical
J3, J13, J15, J17, J18, J21: Conn_02x04_Odd_Even; PinHeader_2x04_P2.54mm_Vertical
J4, J5: Conn_01x20; PinSocket_1x20_P2.54mm_Vertical
J6, J28: Conn_02x20; PinHeader_2x20_P2.54mm_Vertical
J7: VIRTUAL_MPU6050; PinSocket_1x08_P2.54mm_Vertical
J12: Screw_Terminal_01x04; TerminalBlock_Phoenix_MKDS-1,5-4-5.08_1x04_P5.08mm_Horizont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
J14: OLED_SOCKET; PinSocket_1x04_P2.54mm_Vertical
J16: I2C_Selector; PinHeader_2x03_P2.54mm_Vertical
J25: BME; PinSocket_1x06_P2.54mm_Vertical
J26, J30, J37: Servo; PinHeader_1x03_P2.54mm_Vertical
J29, J34: Sig_Servo; PinHeader_1x01_P2.54mm_Vertical
J32: Power_Servo_Selector; PinHeader_1x03_P2.54mm_Vertical
J35: HC-SR04_VIRTUAL; PinSocket_1x04_P2.54mm_Vertical
J36: Power_Selector; PinHeader_1x03_P2.54mm_Vertical
J40: Conn_01x08_Socket; PinSocket_1x08_P2.54mm_Vertical
JP1, JP2, JP3, JP30: Jumper_2.54mm_red
JP4, JP5, JP6, JP7, JP10, JP11, JP12, JP13, JP14, JP15, JP16, JP17, JP18, JP19, JP20, JP21, JP22, JP23, JP24, JP25, JP26, JP27, JP28, JP29: Jumper_2.54mm_green
JP8, JP9: Jumper_2.54mm_blue
LDR1: LDR07; R_LDR_5.1x4.3mm_P3.4mm_Vertical
M1, M2: Motor_DC; PinHeader_1x01_P2.54mm_Vertical
OLED1: SSD1306_OLED_Display_VIRTUAL_128_64
Q3: 2N7002; TO-92_Inline
Q4: IRF520; TO-220-3_Vertical
R1, R2, R3, R4, R11, R15, R16, R20: 10k; R_Axial_DIN0207_L6.3mm_D2.5mm_P10.16mm_Horizontal
R5, R6, R7, R8, R9, R12, R13, R14, R17, R18, R21: 270; R_Axial_DIN0207_L6.3mm_D2.5mm_P10.16mm_Horizontal
R10, R19, R33, R34, R35, R36, R37, R38, R39, R40: 1k; R_Axial_DIN0207_L6.3mm_D2.5mm_P10.16mm_Horizontal
RV1: R_Potentiometer; Potentiometer_Alps_RK163_Single_Horizontal
S1, S2, S3, S4: Spacer_M3_FF_20mm
SERVO_SG1: SG90_Servo
SW1, SW7: SW_Left; SW_PUSH_6mm
SW2: SW_Up; SW_PUSH_6mm
SW3, SW5, SW8: SW_Right; SW_PUSH_6mm
SW4: SW_Down; SW_PUSH_6mm
SW6: RotaryEncoder_Switch; RotaryEncoder
SW9: SW_Reset; SW_PUSH_6mm
U1, U6, U7, U8, U9: PC817_SMD; SMDIP-4_W9.53mm
U2: L293D; DIP-16_W7.62mm_Socket
U3: NRF24L01_Breakout_socket; nRF24L01_Breakout
U4: DS3231M; SOIC-16W_7.5x10.3mm_P1.27mm
U5: 74HC04; DIP-14_W7.62mm_Socket
U10: BME280_Breakout
U11: nRF24L01_Virtual
U12: PCA9635; TSSOP-28_4.4x9.7mm_P0.65mm
U13, U14: ST890
V1: VIRTUAL_FOOTPRINT

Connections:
+3.3V: J2.4, J8.4, J14.3, J17.1, J17.2, J17.3, J17.4, J17.5, J17.6, J17.7, J17.8, J36.1, R9.2, R10.2, R15.1, R18.2, RV1.1, SW1.1, SW2.1, SW3.1, SW4.1, SW6.S2, U3.2 (VCC), U4.2 (VCC), U4.4 (~RST), U12.28 (VDD), U13.6 (OUT), U13.7 (OUT)
+5V: D5.2 (A), J18.1, J18.2, J18.3, J18.4, J18.5, J18.6, J18.7, J18.8, J32.1, J36.3, R5.1, U14.6 (OUT), U14.7 (OUT)
/DEFAULT_LED: J28.8, R8.1
/HC-SR04/ECHO: J23.3, J28.4
/HC-SR04/GND: J23.4, J37.3
/HC-SR04/TRIG: J23.2, J28.2
/IO_Extender/LED_1: R13.1, U12.9 (LED3)
/IO_Extender/LED_2: R14.1, U12.10 (LED4)
/IO_Extender/LED_3: R6.1, U12.11 (LED5)
/IO_Extender/LED_4: R7.1, U12.12 (LED6)
/IO_Extender/LED_5: R12.1, U12.13 (LED7)
/MCU/+3.3V: D12.2 (A), J6.10, J15.2, J15.4, J15.6, J15.8, U13.1 (IN), U13.2 (IN)
/MCU/GND: J6.6, J6.16, J6.26, J6.36, J13.1, J13.3, J13.5, J13.7, J28.6, J28.16, J28.26, J28.36, SW9.2
/MCU/GP0: J28.40, R33.2
/MCU/GP1: J28.38, R35.2
/MCU/GP2: J28.34, R39.2
/MCU/GP3: J28.32, R37.2
/MCU/GP6: J28.24, SW6.B
/MCU/GP7: J28.22, SW6.A
/MCU/GP8: J28.20, R11.1, SW6.S1
/MCU/GP9: J28.18, R2.1, SW2.2
/MCU/GP10: J28.14, R4.1, SW4.2
/MCU/GP11: J28.12, R1.1, SW1.2
/MCU/GP12: J28.10, R3.1, SW3.2
/MCU/GP16: J6.40, U3.7 (MISO)
/MCU/GP17: D7.2 (A), J6.38
/MCU/GP18: J6.34, U3.5 (SCK)
/MCU/GP19: J6.32, U3.6 (MOSI)
/MCU/GP20: J6.30, U3.3 (CE)
/MCU/GP21: J6.28, U3.4 (~CSN)
/MCU/GP26: J6.20, RV1.2
/MCU/GP27: J6.18, LDR1.1, R15.2
/MCU/RUN: J5.11, J6.21, J6.22, SW9.1
/Motors/L239D_Interfaces/5V_Power: D5.1 (K), R34.2, R36.2, R38.2, R40.2, U5.14 (VCC)
/Motors/L239D_Interfaces/DIR_M1_A: U2.2 (1A), U5.2
/Motors/L239D_Interfaces/DIR_M1_B: R34.1, U2.7 (2A), U5.1, U6.4
/Motors/L239D_Interfaces/DIR_M2_A: U2.10 (3A), U5.12
/Motors/L239D_Interfaces/DIR_M2_B: R40.1, U2.15 (4A), U5.13, U8.4
/Motors/L239D_Interfaces/EN_M1_OUT: U2.1 (EN1,2), U5.6
/Motors/L239D_Interfaces/EN_M2_OUT: U2.9 (EN3,4), U5.8
/OLED/A: J14.1, J16.4
/OLED/B: J14.2, J16.3
/Power_Supply1/IN: D13.2 (A), J6.2, U14.1 (IN), U14.2 (IN)
/SCL: J2.3, J8.3, J13.2, J13.4, J13.6, J13.8, J16.5, J16.6, J25.4, J28.28, J40.4, U4.16 (SCL), U12.26 (SCL)
/SDA: J2.2, J8.2, J15.1, J15.3, J15.5, J15.7, J16.1, J16.2, J25.3, J28.30, J40.3, U4.15 (SDA), U12.27 (SDA)
/SERVO_1: J37.2, U12.6 (LED0)
/Sensors/VCC_Sensor: J25.6, J36.2
/Servo_Power/Ext_Servo: J32.3, J33.1
GND: BT1.2 (-), D1.1 (K), D2.1 (K), D3.1 (K), D4.1 (K), D9.1 (K), D10.1 (K), D11.1 (K), J2.1, J3.1, J3.2, J3.3, J3.4, J3.5, J3.6, J3.7, J3.8, J8.1, J12.4, J14.4, J21.1, J21.2, J21.3, J21.4, J21.5, J21.6, J21.7, J21.8, J25.5, J26.3, J30.3, J33.2, LDR1.2, Q4.3 (S), R1.2, R2.2, R3.2, R4.2, R11.2, R20.2, RV1.3, SW5.2, SW6.C, SW8.2, U1.3, U3.1 (GND), U4.5 (GND), U4.6 (GND), U4.7 (GND), U4.8 (GND), U4.9 (GND), U4.10 (GND), U4.11 (GND), U4.12 (GND), U4.13 (GND), U6.2, U6.3, U7.2, U7.3, U8.2, U8.3, U9.2, U9.3, U12.14 (VSS), U13.3 (~ON), U13.4 (GND), U14.3 (~ON), U14.4 (GND)
GND_MOS: Q3.1 (S), R16.1, U1.2
GND_POWER: U2.4 (GND), U2.5 (GND), U2.12 (GND), U2.13 (GND), U5.7 (GND)
unnamed: BT1.1 (+), U4.14 (VBAT)
unnamed: D1.2 (A), R7.2
unnamed: D2.2 (A), R14.2
unnamed: D3.2 (A), R8.2
unnamed: D4.2 (A), R5.2
unnamed: D6.2 (A), J12.3, Q4.2 (D)
unnamed: D6.1 (K), J12.1, J12.2, R19.1
unnamed: D7.1 (K), Q3.2 (G), R16.2, SW7.1
unnamed: D8.2 (A), U4.3 (~INT/SQW)
unnamed: D8.1 (K), R9.1
unnamed: D9.2 (A), R12.2
unnamed: D10.2 (A), R13.2
unnamed: D11.2 (A), R6.2
unnamed: D12.1 (K), R17.1
unnamed: D13.1 (K), R21.1
unnamed: J1.1, U2.3 (1Y)
unnamed: J1.2, U2.6 (2Y)
unnamed: J5.1, J6.1
unnamed: J5.2, J6.3
unnamed: J5.3, J6.5
unnamed: J5.4, J6.7
unnamed: J5.5, J6.9
unnamed: J5.6, J6.11
unnamed: J5.7, J6.13
unnamed: J5.8, J6.15
unnamed: J5.9, J6.17
unnamed: J5.10, J6.19
unnamed: J5.12, J6.23
unnamed: J5.13, J6.25
unnamed: J5.14, J6.27
unnamed: J5.15, J6.29
unnamed: J5.16, J6.31
unnamed: J5.17, J6.33
unnamed: J5.18, J6.35
unnamed: J5.19, J6.37
unnamed: J5.20, J6.39
unnamed: J11.1, U2.11 (3Y)
unnamed: J11.2, U2.14 (4Y)
unnamed: J19.1, U2.8 (VCC2), U2.16 (VCC1)
unnamed: J26.1, J29.1
unnamed: J26.2, J30.2, J32.2
unnamed: J4.1, J28.1
unnamed: J4.2, J28.3
unnamed: J4.3, J28.5
unnamed: J4.4, J28.7
unnamed: J4.5, J28.9
unnamed: J4.6, J28.11
unnamed: J4.7, J28.13
unnamed: J4.8, J28.15
unnamed: J4.9, J28.17
unnamed: J4.10, J28.19
unnamed: J4.11, J28.21
unnamed: J4.12, J28.23
unnamed: J4.13, J28.25
unnamed: J4.14, J28.27
unnamed: J4.15, J28.29
unnamed: J4.16, J28.31
unnamed: J4.17, J28.33
unnamed: J4.18, J28.35
unnamed: J4.19, J28.37
unnamed: J4.20, J28.39
unnamed: J30.1, J34.1
unnamed: Q3.3 (D), R18.1, U1.1
unnamed: Q4.1 (G), R19.2, R20.1, U1.4
unnamed: R10.1, SW7.2
unnamed: R33.1, U6.1
unnamed: R35.1, U7.1
unnamed: R36.1, SW8.1, U5.5, U7.4
unnamed: R37.1, U9.1
unnamed: R38.1, SW5.1, U5.9, U9.4
unnamed: R39.1, U8.1
unnamed: R17.2, U13.8 (~FAULT)
unnamed: R21.2, U14.8 (~FAULT)

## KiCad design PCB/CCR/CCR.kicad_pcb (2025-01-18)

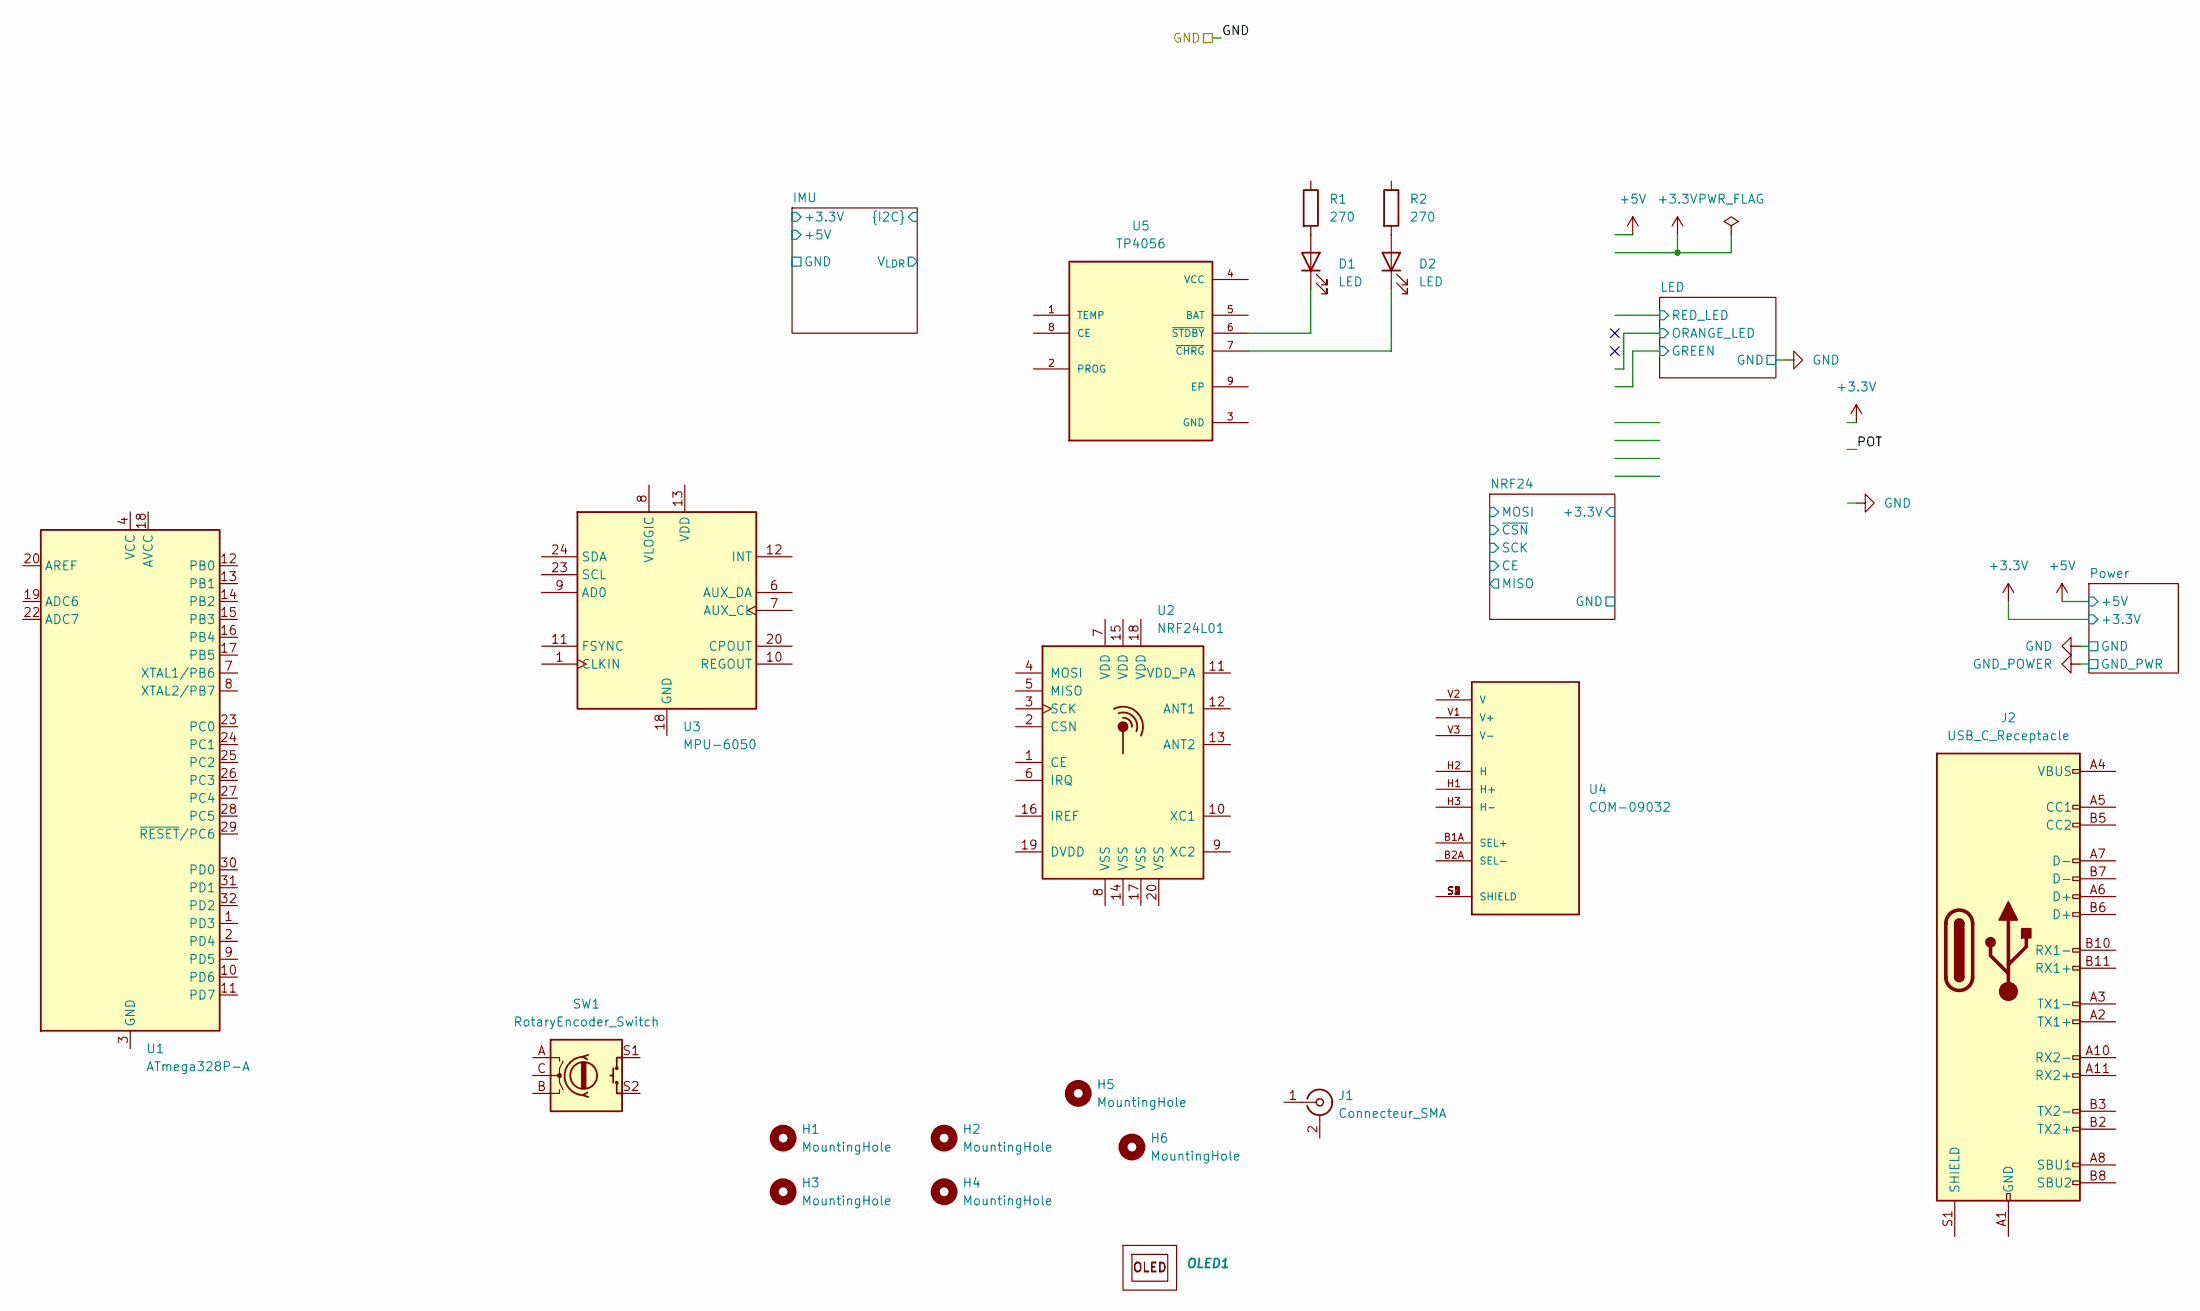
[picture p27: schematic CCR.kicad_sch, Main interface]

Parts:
D1, D2: LED; LED_0603_1608Metric
H1, H2, H3, H4, H5, H6: MountingHole; MountingHole_3.2mm_M3
J1: Connecteur_SMA; SMA_Amphenol_132289_EdgeMount
J2: USB_C_Receptacle; USB_C_Receptacle_GCT_USB4085
OLED1: SSD1306_OLED_Display_VIRTUAL_128_64
R1, R2: 270; R_0603_1608Metric
SW1: RotaryEncoder_Switch; RotaryEncoder
U1: ATmega328P-A; TQFP-32_7x7mm_P0.8mm
U2: NRF24L01; QFN-20-1EP_4x4mm_P0.5mm_EP2.5x2.5mm
U3: MPU-6050; InvenSense_QFN-24_4x4mm_P0.5mm
U4: COM-09032; XDCR_COM-09032; PARTREV N/A
U5: TP4056; SOP127P600X175-9N

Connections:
unnamed: D1.2 (A), R1.2
unnamed: D1.1 (K), U5.6 (~STDBY)
unnamed: D2.2 (A), R2.2
unnamed: D2.1 (K), U5.7 (~CHRG)
unnamed: J2.A1 (GND), J2.A12 (GND), J2.B1 (GND), J2.B12 (GND)
unnamed: J2.A4 (VBUS), J2.A9 (VBUS), J2.B4 (VBUS), J2.B9 (VBUS)
unnamed: U1.3 (GND), U1.5 (GND), U1.21 (GND)
unnamed: U1.4 (VCC), U1.6 (VCC)
unnamed: U4.S1 (SHIELD), U4.S2 (SHIELD), U4.S3 (SHIELD), U4.S4 (SHIELD)

Board: 2 copper layers, 20 parts (1 on the bottom side), 9 nets, no tracks yet.

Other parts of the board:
V1: VIRTUAL_FOOTPRINT

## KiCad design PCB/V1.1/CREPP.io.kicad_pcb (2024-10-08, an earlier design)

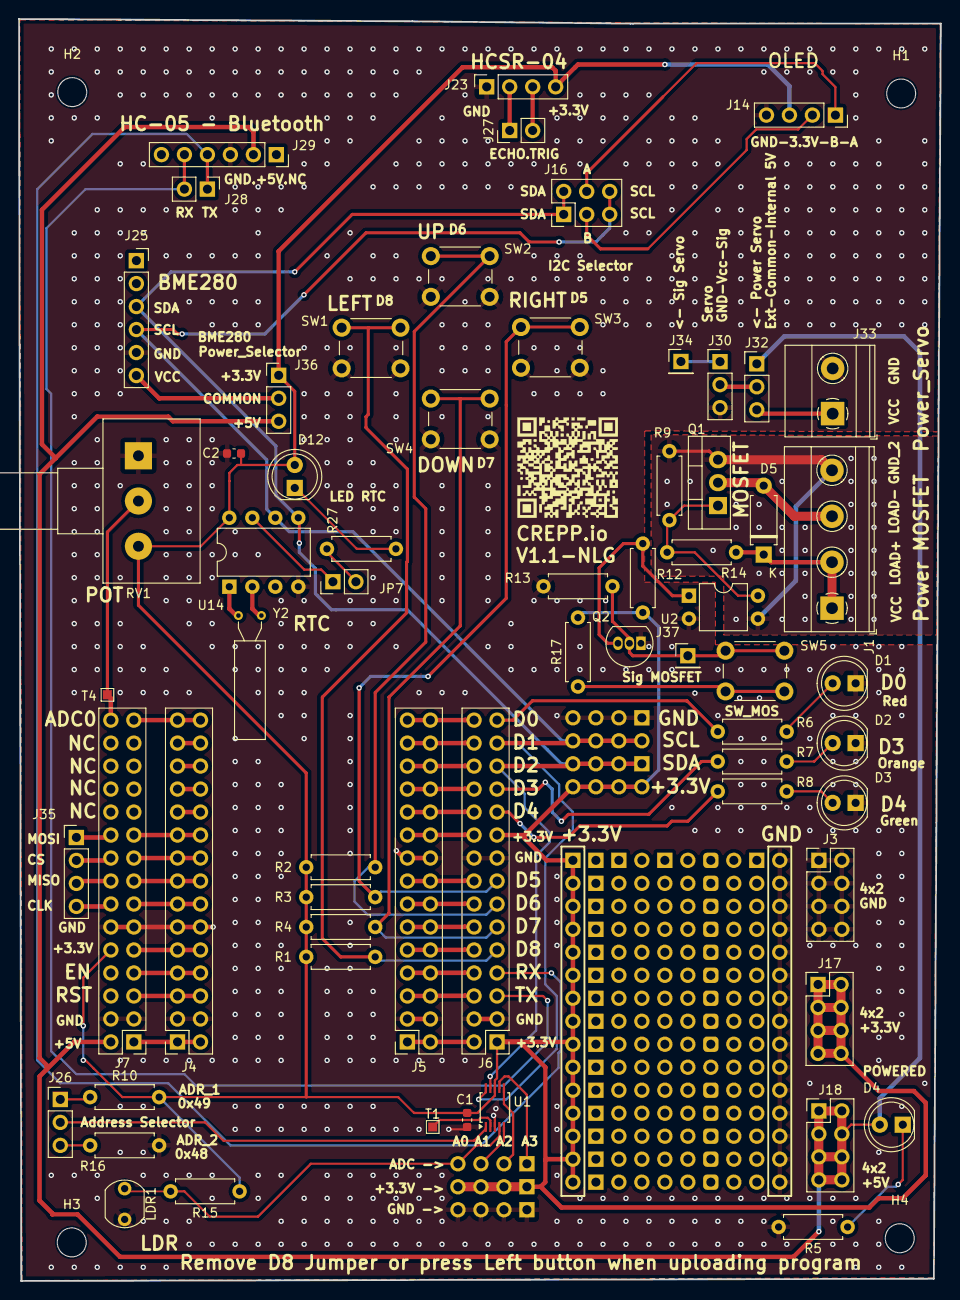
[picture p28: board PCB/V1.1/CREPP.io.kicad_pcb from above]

Board: 2 copper layers, 101.9 x 139.4 mm, 78 parts (0 on the bottom side), 77 nets.

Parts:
C1, C2: 100nF; C_0603_1608Metric
D1, D2, D3, D4, D12: LED; LED_D5.0mm
D5: D; D_A-405_P7.62mm_Horizontal
H1, H2, H3, H4: MountingHole; MountingHole_3.2mm_M3
J1: Screw_Terminal_01x04; TerminalBlock_Phoenix_MKDS-1,5-4-5.08_1x04_P5.08mm_Horizont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
J3, J13, J15, J17, J18: Conn_02x04_Odd_Even; PinHeader_2x04_P2.54mm_Vertical
J4, J5: Right_Connector; PinSocket_2x15_P2.54mm_Vertical
J6, J8, J9, J10, J11, J12: Right_Connector; PinHeader_2x15_P2.54mm_Vertical
J7: Left_Connector; PinHeader_2x15_P2.54mm_Vertical
J14: OLED_SOCKET; PinSocket_1x04_P2.54mm_Vertical
J16: I2C_Selector; PinHeader_2x03_P2.54mm_Vertical
J19: Analog_Inputs; PinHeader_1x04_P2.54mm_Vertical
J20: GND_Analog; PinHeader_1x04_P2.54mm_Vertical
J21: +3.3V_Analog; PinHeader_1x04_P2.54mm_Vertical
J23: HC-SR; PinSocket_1x04_P2.54mm_Vertical
J25: BME; PinSocket_1x06_P2.54mm_Vertical
J26: Addr_Selector; PinHeader_1x03_P2.54mm_Vertical
J27: SIG_HCSR04; PinHeader_1x02_P2.54mm_Vertical
J28: SIG_HC-05; PinHeader_1x02_P2.54mm_Vertical
J29: Conn_01x06_Socket; PinSocket_1x06_P2.54mm_Vertical
J30: Servo; PinHeader_1x03_P2.54mm_Vertical
J32: Power_Servo_Selector; PinHeader_1x03_P2.54mm_Vertical
J33: Screw_Terminal_01x02; TerminalBlock_Phoenix_MKDS-1,5-2_1x02_P5.00mm_Horizontal
J34: Sig_Servo; PinHeader_1x01_P2.54mm_Vertical
J35: SPI_Connector; PinHeader_1x04_P2.54mm_Vertical
J36: Power_Selector; PinHeader_1x03_P2.54mm_Vertical
J37: Sig_MOSFET; PinHeader_1x01_P2.54mm_Vertical
JP7: Jumper; PinHeader_1x02_P2.54mm_Vertical
LDR1: LDR07; R_LDR_5.1x4.3mm_P3.4mm_Vertical
Q1: IRF520; TO-220-3_Vertical
Q2: 2N7000; TO-92_Inline
R1, R2, R3, R4, R9, R10, R13, R15, R16: 10k; R_Axial_DIN0207_L6.3mm_D2.5mm_P7.62mm_Horizontal
R5, R6, R7, R8, R12, R27: 270; R_Axial_DIN0207_L6.3mm_D2.5mm_P7.62mm_Horizontal
R14, R17: 1k; R_Axial_DIN0207_L6.3mm_D2.5mm_P7.62mm_Horizontal
RV1: R_Potentiometer; Potentiometer_Alps_RK163_Single_Horizontal
SW1, SW5: SW_Left; SW_PUSH_6mm
SW2: SW_Up; SW_PUSH_6mm
SW3: SW_Right; SW_PUSH_6mm
SW4: SW_Down; SW_PUSH_6mm
T1, T4: TestPoint; TestPoint_Pad_1.0x1.0mm
U1: ADS1115IDGS; TSSOP-10_3x3mm_P0.5mm
U2: PC817; DIP-4_W7.62mm
U14: DS1307+; DIP-8_W7.62mm
Y2: 16MHz; Crystal_AT310_D3.0mm_L10.0mm_Horizontal

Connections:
+3.3V: C1.1, C2.1, D12.2 (A), J6.1, J6.19, J7.10, J12.1, J12.3, J12.5, J12.7, J12.9, J12.11, J12.13, J12.15, J12.17, J12.19, J12.21, J12.23, J12.25, J12.27, J12.29, J14.3, J15.2, J15.4, J15.6, J15.8, J17.1, J17.2, J17.3, J17.4, J17.5, J17.6, J17.7, J17.8, J21.1, J21.2, J21.3, J21.4, J23.4, J36.1, R1.1, R2.1, R3.1, R4.1, R10.2, R12.2, R15.1, R17.2, RV1.3, U1.8 (VDD), U14.8 (VCC)
+5V: D4.2 (A), J7.2, J18.1, J18.2, J18.3, J18.4, J18.5, J18.6, J18.7, J18.8, J29.2, J32.1, J36.3
/Bluetooth/RX: J6.7, J28.1, J29.4
/Bluetooth/TX: J6.5, J28.2, J29.5
/IO_Extender/A1: J19.3, U1.5 (AIN1)
/IO_Extender/A2: J19.2, U1.6 (AIN2)
/IO_Extender/A3: J19.1, U1.7 (AIN3)
/IO_Extender/SCL: J6.27, J13.2, J13.4, J13.6, J13.8, J16.5, J16.6, J25.4, U1.10 (SCL), U14.6 (SCL)
/IO_Extender/SDA: J6.25, J15.1, J15.3, J15.5, J15.7, J16.1, J16.2, J25.3, U1.9 (SDA), U14.5 (SDA)
/LDR: J19.4, LDR1.1, R15.2, U1.4 (AIN0)
/LED/GREEN: J6.21, R8.1
/LED/ORANGE_LED: J6.23, R7.1
/LED/RED_LED: J6.29, R6.1
/MCU/CLK: J7.14, J35.4
/MCU/CS: J7.18, J35.2
/MCU/GPIO12_D6: J6.13, R2.2, SW2.1
/MCU/GPIO13_D7_RX2: J6.11, R4.2, SW4.1
/MCU/GPIO14_D5: J6.15, R3.2, SW3.1
/MCU/GPIO15_D8_TX2: J6.9, R1.2, SW1.1
/MCU/MISO: J7.16, J35.3
/MCU/MOSI: J7.20, J35.1
/MCU/Pin_1: J4.1, J4.2, J7.1
/MCU/Pin_2: J5.1, J5.2, J6.2
/MCU/Pin_5: J4.5, J4.6, J7.5
/MCU/Pin_6: J5.5, J5.6, J6.6
/MCU/Pin_7: J4.7, J4.8, J7.7
/MCU/Pin_8: J5.7, J5.8, J6.8
/MCU/Pin_9: J4.9, J4.10, J7.9
/MCU/Pin_10: J5.9, J5.10, J6.10
/MCU/Pin_12: J5.11, J5.12, J6.12
/MCU/Pin_13: J4.13, J4.14, J7.13
/MCU/Pin_14: J5.13, J5.14, J6.14
/MCU/Pin_15: J4.15, J4.16, J7.15
/MCU/Pin_16: J5.15, J5.16, J6.16
/MCU/Pin_17: J4.17, J4.18, J7.17
/MCU/Pin_19: J4.19, J4.20, J7.19
/MCU/Pin_20: J5.19, J5.20, J6.20
/MCU/Pin_21: J4.21, J4.22
/MCU/Pin_22: J5.21, J5.22, J6.22
/MCU/Pin_23: J4.23, J4.24
/MCU/Pin_24: J5.23, J5.24, J6.24
/MCU/Pin_25: J4.25, J4.26
/MCU/Pin_26: J5.25, J5.26, J6.26
/MCU/Pin_27: J4.27, J4.28
/MCU/Pin_28: J5.27, J5.28, J6.28
/MCU/Pin_29: J4.29, J4.30, J7.29
/MCU/Pin_30: J5.29, J5.30, J6.30
/OLED/A: J14.1, J16.4
/OLED/B: J14.2, J16.3
/POT: J7.30, RV1.2, T4.1
/Power/Ext_Servo: J32.3, J33.1
/Sensors/VCC_Sensor: J25.6, J36.2
GND: C1.2, C2.2, D1.1 (K), D2.1 (K), D3.1 (K), J3.1, J3.2, J3.3, J3.4, J3.5, J3.6, J3.7, J3.8, J4.3, J4.4, J4.11, J4.12, J5.3, J5.4, J5.17, J5.18, J6.3, J6.4, J6.17, J6.18, J7.3, J7.4, J7.11, J7.12, J8.2, J8.4, J8.6, J8.8, J8.10, J8.12, J8.14, J8.16, J8.18, J8.20, J8.22, J8.24, J8.26, J8.28, J8.30, J13.1, J13.3, J13.5, J13.7, J14.4, J20.1, J20.2, J20.3, J20.4, J23.1, J25.5, J29.3, J30.3, J33.2, LDR1.2, Q2.1 (S), R5.2, R13.1, R16.2, RV1.1, SW1.2, SW2.2, SW3.2, SW4.2, U1.3 (GND), U2.2, U14.4 (GND)
GND_POWER: J1.4, Q1.3 (S), R9.2, U2.3
unnamed: D1.2 (A), R6.2
unnamed: D2.2 (A), R7.2
unnamed: D3.2 (A), R8.2
unnamed: D4.1 (K), R5.1
unnamed: D5.2 (A), J1.3, Q1.2 (D)
unnamed: D5.1 (K), J1.1, J1.2, R14.1
unnamed: D12.1 (K), R27.1
unnamed: J23.2, J27.1
unnamed: J23.3, J27.2
unnamed: J26.1, R10.1
unnamed: J26.2, U1.1 (ADDR)
unnamed: J26.3, R16.1
unnamed: J30.1, J34.1
unnamed: J30.2, J32.2
unnamed: J37.1, Q2.2 (G), R13.2, SW5.1
unnamed: JP7.1 (A), U14.7 (SQW/OUT)
unnamed: JP7.2 (B), R27.2
unnamed: Q1.1 (G), R9.1, R14.2, U2.4
unnamed: Q2.3 (D), R12.1, U2.1
unnamed: R17.1, SW5.2
unnamed: T1.1, U1.2 (ALERT/RDY)
unnamed: U14.1 (X1), Y2.1
unnamed: U14.2 (X2), Y2.2

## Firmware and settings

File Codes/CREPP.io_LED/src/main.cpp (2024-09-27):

/*!
CREPP.io code
Ce code permet de tester le bon fonctionnement des LEDs intégrés à la carte.
Ne pas oublier de mettre les jumpers associés (D0, D3 et D4)
*/
#include <Arduino.h> 

#define RED_LED D0

#define ORANGE_LED D3
#define GREEN_LED D4

/*
Fonction qui ne retourne aucun élément et qui prend en paramètre : 
- Une broche de LED
- Une durée de clignotement (en millisecondes)
*/
void blinkLed(uint8_t led, uint16_t time)
{
  digitalWrite(led, HIGH);
  delay(time);
  digitalWrite(led, LOW);
  delay(time);
}

void setup() 
{
    Serial.begin(115200);         //Initialise la communication série
    pinMode(RED_LED, OUTPUT);     //Broche en sortie
    pinMode(ORANGE_LED, OUTPUT);  //Broche en sortie
    pinMode(GREEN_LED, OUTPUT);   //Broche en sortie
    Serial.println("INIT : OK");
}



void loop() 
{ 
  blinkLed(RED_LED, 100);  // Allume la LED rouge pendant 1 seconde
  blinkLed(ORANGE_LED, 150); // Allume la LED orange pendant 0.5 seconde
  blinkLed(GREEN_LED, 200); // Allume la LED verte pendant 0.25 seconde

}

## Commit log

2024-08-29 Update of README
    [BOM_CREPP.io.csv, Bluetooth.kicad_sch, CREPP.io.kicad_pcb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]
2024-09-15 Update of doc
    [CREPP.io.kicad_pcb]
2024-09-27 Update codes for LED and Potentiometer
    [CREPP.io.kicad_pcb]
2024-09-30 Update of Doc, add code for buttons
2024-10-06 Add V1.1
    [Bluetooth.kicad_sch, CREPP.io.kicad_pcb, CREPP.io.kicad_sch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]
2024-10-06 Test URl MD
    [CREPP.io-B_Cu.gbr, CREPP.io-B_Fab.gbr, CREPP.io-B_Mask.gbr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]
2024-10-06 Add md list
    [CREPP.io.csv]
2024-10-06 Add Assembly file
2024-10-17 Add code
    [CREPP.io.kicad_pcb]
2024-11-14 Update 2.0 - IMU and NRF24 support
    [CREPP.io.kicad_pcb, CREPP.io.kicad_sch, IMU.kicad_sch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]
2024-11-19 Add RTC
    [CREPP.io.kicad_pcb, CREPP.io.kicad_sch, IO_Extender.kicad_sch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]
2024-11-22 Add codes
    [CREPP.io.kicad_pcb, CREPP.io.kicad_sch]
2024-12-31 Update V2.0 form factor
    [CREPP.io.kicad_pcb, CREPP.io.kicad_sch, I2C_Interface.kicad_sch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]
2025-01-01 Add img
    [CREPP.io.kicad_pcb, CREPP.io.kicad_sch, I2C_Interface.kicad_sch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]
2025-01-02 Add Crepp COntrol Remote
    [Bluetooth.kicad_sch, CCR.kicad_pcb, CCR.kicad_sch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]
2025-01-18 Update of BME and OLED
    [AA_14500 Battery Holder.step, CCR.kicad_pcb, CCR.kicad_sch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]
2025-02-07 Update board
    [CREPP.io.kicad_pcb, CREPP.io.kicad_sch, I2C_Interface.kicad_sch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]
